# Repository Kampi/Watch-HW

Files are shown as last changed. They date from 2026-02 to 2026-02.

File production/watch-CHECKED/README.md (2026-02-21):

<p align="center" width="100%">
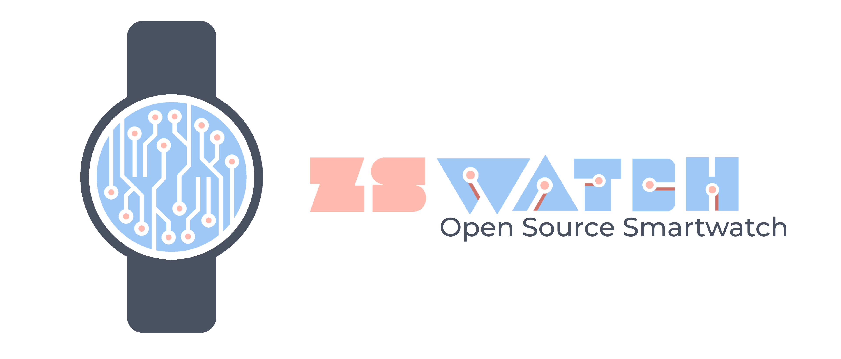
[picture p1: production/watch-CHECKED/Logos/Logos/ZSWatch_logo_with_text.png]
  
</p>

<h1 align="center">Watch-DevKit-HW</h1>

<p align="center" width="100%">
  <a href="https://github.com/ZSWatch/Watch-DevKit-HW/actions/workflows/watch.yaml">
    
  </a>
</p>

***

<p align="center">
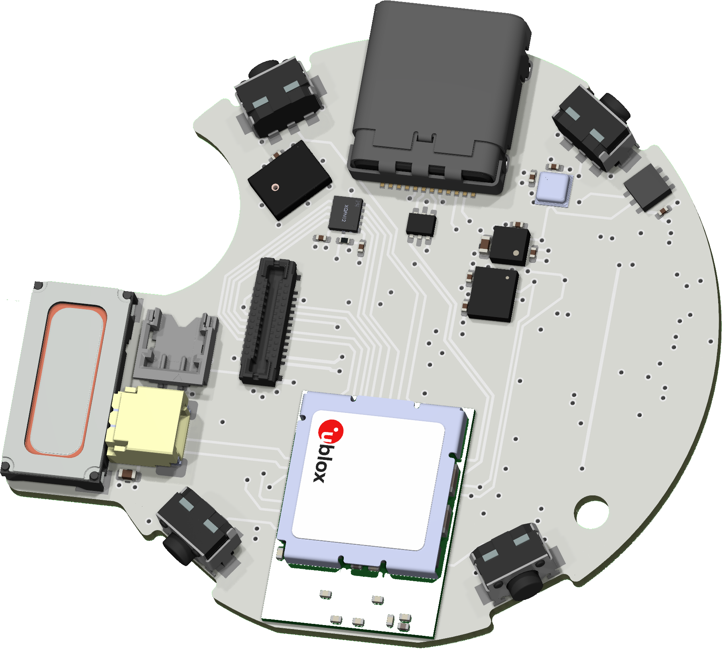
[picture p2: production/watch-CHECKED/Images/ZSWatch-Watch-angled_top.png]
3D Top Angled
  
&nbsp; &nbsp; &nbsp; &nbsp;
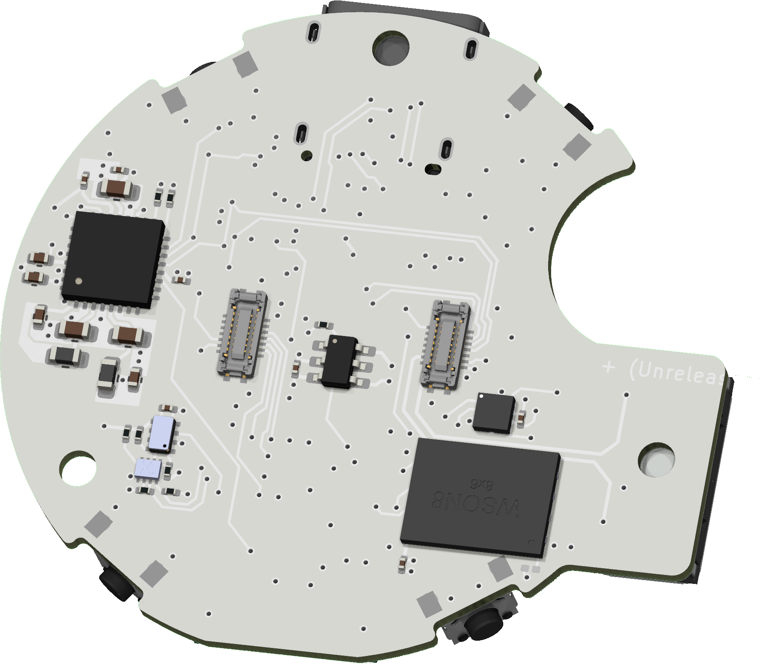
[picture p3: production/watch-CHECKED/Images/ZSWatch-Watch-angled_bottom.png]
3D Bottom Angled
  
</p>

***

## SPECIFICATIONS

| Parameter | Value |
| --- | --- |
| Dimensions | 40.97 × 37.5 mm |

***

## DIRECTORY STRUCTURE

    .
    ├─ Computations       # Misc calculations
    ├─ HTML               # HTML files for generated webpage
    ├─ Images             # Pictures and renders
    │
    ├─ kibot_resources    # External resources for KiBot
    │  ├─ colors          # Color theme for KiCad
    │  ├─ fonts           # Fonts used in the project
    │  ├─ scripts         # External scripts used with KiBot
    │  └─ templates       # Templates for KiBot generated reports
    │
    ├─ kibot_yaml         # KiBot YAML config files
    ├─ KiRI               # KiRI (PCB diff viewer) files
    │
    ├─ lib                # KiCad footprint and symbol libraries
    │  ├─ 3d_models       # Component 3D models
    │  ├─ lib_fp          # Footprint libraries
    │  └─ lib_sym         # Symbol libraries
    │
    ├─ logos              # Logos
    │
    ├─ Manufacturing      # Assembly and fabrication documents
    │  ├─ Assembly        # Assembly documents (BoM, pos, notes)
    │  │
    │  └─ Fabrication     # Fabrication documents (ZIP, notes)
    │     ├─ Drill Tables # CSV drill tables
    │     └─ Gerbers      # Gerbers
    │
    ├─ Report             # Reports for ERC/DRC
    ├─ Schematic          # PDF of schematic
    ├─ templates          # Title block templates
    ├─ Testing
    │  └─ Testpoints      # Testpoints tables
    │
    └─ Variants           # Outputs for assembly variants

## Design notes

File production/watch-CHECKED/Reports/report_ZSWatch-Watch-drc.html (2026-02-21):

Logo

| DRC report for ZSWatch-Watch
| PCB: ZSWatch-Watch Revision: + (Unreleased) Date: 2026-02-21T13:06:36+0000 KiCad Version: 9.0.7 | Errors: 1 Warnings: 65 Total: 66

Violations

Type | Description | Details
copper_edge_clearance | Board edge clearance violation (board setup constraints edge clearance 0.1250 mm; actual 0.0000 mm) | @(185.005263 mm, 138.299996 mm): Segment on Edge.Cuts @(187.425537 mm, 138.528148 mm): PCB text '+ (Unreleased)' on B.Cu
lib_footprint_issues | The current configuration does not include the footprint library 'Package_QFN'. | @(202.45 mm, 131.19 mm): Footprint IC604
lib_footprint_mismatch | Footprint 'C_0201_0603Metric' does not match copy in library 'Capacitor_SMD'. | @(203.7 mm, 133.1 mm): Footprint C603
lib_footprint_issues | The current configuration does not include the footprint library 'Wuerth'. | @(216.7 mm, 124.7 mm): Footprint S501
lib_footprint_mismatch | Footprint 'C_0201_0603Metric' does not match copy in library 'Capacitor_SMD'. | @(210.507497 mm, 136.062499 mm): Footprint C504
lib_footprint_mismatch | Footprint 'C_0402_1005Metric' does not match copy in library 'Capacitor_SMD'. | @(192.325 mm, 148.675 mm): Footprint C403
lib_footprint_issues | The current configuration does not include the footprint library 'Wuerth'. | @(197.409401 mm, 152.152416 mm): Footprint S504
lib_footprint_mismatch | Footprint 'C_0201_0603Metric' does not match copy in library 'Capacitor_SMD'. | @(201.23 mm, 132.79 mm): Footprint C604
lib_footprint_mismatch | Footprint 'C_0201_0603Metric' does not match copy in library 'Capacitor_SMD'. | @(213.976079 mm, 132.307498 mm): Footprint C507
lib_footprint_mismatch | Footprint 'R_0201_0603Metric' does not match copy in library 'Resistor_SMD'. | @(202.63 mm, 132.79 mm): Footprint R613
lib_footprint_mismatch | Footprint 'C_0201_0603Metric' does not match copy in library 'Capacitor_SMD'. | @(210.462496 mm, 134.237499 mm): Footprint C503
lib_footprint_mismatch | Footprint 'C_0201_0603Metric' does not match copy in library 'Capacitor_SMD'. | @(214.282501 mm, 126.8575 mm): Footprint C509
lib_footprint_mismatch | Footprint 'C_0201_0603Metric' does not match copy in library 'Capacitor_SMD'. | @(213.100001 mm, 127.675001 mm): Footprint C508
lib_footprint_issues | The current configuration does not include the footprint library 'EastRising'. | @(199.0 mm, 138.5 mm): Footprint X608
lib_footprint_issues | The current configuration does not include the footprint library 'Package_LGA_Kampi'. | @(212.1 mm, 135.2 mm): Footprint IC502
lib_footprint_issues | The current configuration does not include the footprint library 'Wuerth'. | @(216.6 mm, 152.1 mm): Footprint S502
lib_footprint_mismatch | Footprint 'C_0201_0603Metric' does not match copy in library 'Capacitor_SMD'. | @(212.78 mm, 130.667001 mm): Footprint C505
lib_footprint_mismatch | Footprint 'C_0201_0603Metric' does not match copy in library 'Capacitor_SMD'. | @(197.675287 mm, 128.024713 mm): Footprint C502
lib_footprint_issues | The current configuration does not include the footprint library 'Package_LGA_Kampi'. | @(214.500001 mm, 128.2375 mm): Footprint IC504
lib_footprint_mismatch | Footprint 'JST_SH_SM02B-SRSS-TB_1x02-1MP_P1.00mm_Horizontal' does not match copy in library 'Connector_JST'. | @(192.9 mm, 146.0 mm): Footprint X402
lib_footprint_mismatch | Footprint 'SOT-666' does not match copy in library 'Package_TO_SOT_SMD'. | @(207.0375 mm, 131.35 mm): Footprint IC602
lib_footprint_issues | The current configuration does not include the footprint library 'Molex'. | @(193.95 mm, 140.8 mm): Footprint X509
lib_footprint_issues | The current configuration does not include the footprint library 'Wuerth'. | @(197.433306 mm, 124.890678 mm): Footprint S503
lib_footprint_issues | The current configuration does not include the footprint library 'Knowles'. | @(198.820801 mm, 129.566207 mm): Footprint MK501
lib_footprint_issues | The current configuration does not include the footprint library 'Package_LGA_Kampi'. | @(212.604999 mm, 132.15 mm): Footprint IC503
lib_footprint_issues | The current configuration does not include the footprint library 'Broadcom'. | @(220.146966 mm, 127.633273 mm): Footprint IC501
lib_footprint_issues | The current configuration does not include the footprint library 'uBlox'. | @(207.0 mm, 150.1 mm): Footprint M601
lib_footprint_mismatch | Footprint 'C_0402_1005Metric' does not match copy in library 'Capacitor_SMD'. | @(211.054999 mm, 132.1875 mm): Footprint C506
lib_footprint_mismatch | Footprint 'USB_C_Receptacle_Amphenol_12401610E4-2A' does not match copy in library 'Connector_USB'. | @(207.0 mm, 123.9 mm): Footprint X603
lib_footprint_mismatch | Footprint 'C_0201_0603Metric' does not match copy in library 'Capacitor_SMD'. | @(221.234143 mm, 128.879548 mm): Footprint C501
lib_footprint_issues | The current configuration does not include the footprint library 'Same Sky'. | @(188.0 mm, 143.8 mm): Footprint LS801
lib_footprint_issues | The current configuration does not include the footprint library 'Package_QFN'. | @(197.4 mm, 142.15 mm): Footprint IC505
lib_footprint_mismatch | Footprint 'C_0201_0603Metric' does not match copy in library 'Capacitor_SMD'. | @(216.3304 mm, 136.3 mm): Footprint C402
lib_footprint_mismatch | Footprint 'R_0201_0603Metric' does not match copy in library 'Resistor_SMD'. | @(207.9 mm, 138.0 mm): Footprint R601
lib_footprint_mismatch | Footprint 'R_0201_0603Metric' does not match copy in library 'Resistor_SMD'. | @(216.209999 mm, 148.7 mm): Footprint R501
lib_footprint_mismatch | Footprint 'R_0201_0603Metric' does not match copy in library 'Resistor_SMD'. | @(217.8 mm, 145.5 mm): Footprint R506
lib_footprint_mismatch | Footprint 'R_0201_0603Metric' does not match copy in library 'Resistor_SMD'. | @(214.755 mm, 148.6 mm): Footprint R502
lib_footprint_mismatch | Footprint 'C_0201_0603Metric' does not match copy in library 'Capacitor_SMD'. | @(209.0 mm, 140.7 mm): Footprint C601
lib_footprint_mismatch | Footprint 'C_0201_0603Metric' does not match copy in library 'Capacitor_SMD'. | @(215.755 mm, 143.8 mm): Footprint C511
lib_footprint_mismatch | Footprint 'C_0201_0603Metric' does not match copy in library 'Capacitor_SMD'. | @(220.9 mm, 130.3 mm): Footprint C401
lib_footprint_mismatch | Footprint 'C_0201_0603Metric' does not match copy in library 'Capacitor_SMD'. | @(201.05 mm, 151.355 mm): Footprint C602
lib_footprint_mismatch | Footprint 'C_0603_1608Metric' does not match copy in library 'Capacitor_SMD'. | @(220.761401 mm, 131.497172 mm): Footprint C410
lib_footprint_mismatch | Footprint 'C_0201_0603Metric' does not match copy in library 'Capacitor_SMD'. | @(195.9 mm, 142.2 mm): Footprint C510
lib_footprint_mismatch | Footprint 'C_0603_1608Metric' does not match copy in library 'Capacitor_SMD'. | @(218.622001 mm, 139.936383 mm): Footprint C409
lib_footprint_issues | The current configuration does not include the footprint library 'Amphenol'. | @(200.8 mm, 138.5 mm): Footprint X702
lib_footprint_mismatch | Footprint 'C_0402_1005Metric' does not match copy in library 'Capacitor_SMD'. | @(224.5 mm, 137.1 mm): Footprint C512
lib_footprint_mismatch | Footprint 'C_0402_1005Metric' does not match copy in library 'Capacitor_SMD'. | @(217.892001 mm, 142.308382 mm): Footprint C406
lib_footprint_mismatch | Footprint 'R_0201_0603Metric' does not match copy in library 'Resistor_SMD'. | @(193.87 mm, 150.8 mm): Footprint R612
lib_footprint_mismatch | Footprint 'C_0402_1005Metric' does not match copy in library 'Capacitor_SMD'. | @(224.400001 mm, 135.950002 mm): Footprint C404
lib_footprint_mismatch | Footprint 'L_0603_1608Metric' does not match copy in library 'Inductor_SMD'. | @(221.911 mm, 141.5 mm): Footprint L402
lib_footprint_issues | The current configuration does not include the footprint library 'Package_SON_Kampi'. | @(216.18 mm, 147.5 mm): Footprint IC506
lib_footprint_mismatch | Footprint 'R_0201_0603Metric' does not match copy in library 'Resistor_SMD'. | @(215.109999 mm, 147.420001 mm): Footprint R505
lib_footprint_mismatch | Footprint 'R_0201_0603Metric' does not match copy in library 'Resistor_SMD'. | @(217.75 mm, 131.608381 mm): Footprint R408
lib_footprint_mismatch | Footprint 'C_0402_1005Metric' does not match copy in library 'Capacitor_SMD'. | @(223.8304 mm, 139.278193 mm): Footprint C408
lib_footprint_mismatch | Footprint 'QFN-32-1EP_5x5mm_P0.5mm_EP3.6x3.6mm' does not match copy in library 'Package_DFN_QFN'. | @(220.2 mm, 135.7 mm): Footprint IC401
lib_footprint_mismatch | Footprint 'TSOT-23-6' does not match copy in library 'Package_TO_SOT_SMD'. | @(206.5375 mm, 140.15 mm): Footprint IC601
lib_footprint_mismatch | Footprint 'WSON-8-1EP_8x6mm_P1.27mm_EP3.4x4.3mm' does not match copy in library 'Package_SON'. | @(197.3 mm, 147.135 mm): Footprint IC603
lib_footprint_mismatch | Footprint 'C_0603_1608Metric' does not match copy in library 'Capacitor_SMD'. | @(221.657 mm, 139.936383 mm): Footprint C407
lib_footprint_mismatch | Footprint 'L_0603_1608Metric' does not match copy in library 'Inductor_SMD'. | @(219.370999 mm, 142.349382 mm): Footprint L401
lib_footprint_issues | The current configuration does not include the footprint library 'Micro Crystal'. | @(215.755 mm, 145.430001 mm): Footprint IC507
lib_footprint_mismatch | Footprint 'R_0201_0603Metric' does not match copy in library 'Resistor_SMD'. | @(217.1 mm, 145.5 mm): Footprint R504
lib_footprint_mismatch | Footprint 'R_0201_0603Metric' does not match copy in library 'Resistor_SMD'. | @(218.449999 mm, 131.608381 mm): Footprint R407
lib_footprint_mismatch | Footprint 'C_0201_0603Metric' does not match copy in library 'Capacitor_SMD'. | @(222.730398 mm, 131.087793 mm): Footprint C405
lib_footprint_issues | The current configuration does not include the footprint library 'Amphenol'. | @(212.3 mm, 139.1 mm): Footprint X701

Schematic parity

Type | Description | Details
footprint_symbol_mismatch | Connector_JST:JST_SH_SM02B-SRSS-TB_1x02-1MP_P1.00mm_Horizontal doesn't match footprint given by symbol (JST_SH_SM02B-SRSS-TB_1x02-1MP_P1.00mm_Horizontal). | @(192.9 mm, 146.0 mm): Footprint X402
extra_footprint | Extra footprint | @(220.2 mm, 147.8 mm): Footprint REF**

Generated by KiBot (https://github.com/INTI-CMNB/KiBot/) v1.8.5

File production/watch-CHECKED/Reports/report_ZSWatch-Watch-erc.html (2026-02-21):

Logo

| ERC report for ZSWatch-Watch
| Schematic: ZSWatch-Watch Revision: + (Unreleased) Date: 2026-02-21T13:06:34+0000 KiCad Version: 9.0.7 | Errors: 0 Warnings: 49 Total: 49

Sheet / (ZSWatch-Watch.kicad_sch)

Type | Description | Details
unresolved_variable | Unresolved text variable | @(0.2032 mm, 0.3175 mm): Text Box
unresolved_variable | Unresolved text variable | @(0.2286 mm, 0.3556 mm): Text Box
unresolved_variable | Unresolved text variable | @(0.8636 mm, 0.3175 mm): Text Box
unresolved_variable | Unresolved text variable | @(0.889 mm, 0.3556 mm): Text Box
unresolved_variable | Unresolved text variable | @(1.524 mm, 0.3175 mm): Text Box
unresolved_variable | Unresolved text variable | @(1.5494 mm, 0.3556 mm): Text Box
unresolved_variable | Unresolved text variable | @(2.1844 mm, 0.3175 mm): Text Box
unresolved_variable | Unresolved text variable | @(2.2098 mm, 0.3556 mm): Text Box
footprint_link_issues | The current configuration does not include the footprint library 'Broadcom'. | @(0.3048 mm, 0.5461 mm): Symbol IC501 [APDS-9306-065]
footprint_link_issues | The current configuration does not include the footprint library 'Wuerth'. | @(0.254 mm, 1.0033 mm): Symbol S501 [SW_Push]
footprint_link_issues | The current configuration does not include the footprint library 'Wuerth'. | @(0.254 mm, 1.1176 mm): Symbol S502 [SW_Push]
footprint_link_issues | The current configuration does not include the footprint library 'Wuerth'. | @(0.254 mm, 1.2319 mm): Symbol S503 [SW_Push]
footprint_link_issues | The current configuration does not include the footprint library 'Wuerth'. | @(0.254 mm, 1.3462 mm): Symbol S504 [SW_Push]
footprint_link_issues | The current configuration does not include the footprint library 'Knowles'. | @(0.8636 mm, 1.27 mm): Symbol MK501 [SPK0641HT4H-1]
lib_symbol_issues | The current configuration does not include the symbol library 'Knowles' | @(0.8636 mm, 1.27 mm): Symbol MK501 [SPK0641HT4H-1]
footprint_link_issues | The current configuration does not include the footprint library 'Package_LGA_Kampi'. | @(1.9558 mm, 0.7747 mm): Symbol IC502 [BMI270]
lib_symbol_issues | The current configuration does not include the symbol library 'Bosch_Kampi' | @(1.9558 mm, 0.7747 mm): Symbol IC502 [BMI270]
footprint_link_issues | The current configuration does not include the footprint library 'Package_LGA_Kampi'. | @(2.7051 mm, 0.762 mm): Symbol IC504 [BMP581]
lib_symbol_issues | The current configuration does not include the symbol library 'Bosch_Kampi' | @(2.7051 mm, 0.762 mm): Symbol IC504 [BMP581]
footprint_link_issues | The current configuration does not include the footprint library 'Package_LGA_Kampi'. | @(2.6162 mm, 1.5875 mm): Symbol IC503 [LIS2MDLTR]
lib_symbol_issues | The current configuration does not include the symbol library 'ST' | @(2.6162 mm, 1.5875 mm): Symbol IC503 [LIS2MDLTR]
footprint_link_issues | The current configuration does not include the footprint library 'Package_QFN'. | @(3.3782 mm, 0.6096 mm): Symbol IC505 [DRV2603RUNT]
lib_symbol_issues | The current configuration does not include the symbol library 'Texas Instruments' | @(3.3782 mm, 0.6096 mm): Symbol IC505 [DRV2603RUNT]
footprint_link_issues | The current configuration does not include the footprint library 'Molex'. | @(3.6068 mm, 0.6223 mm): Symbol X509 [Conn_01x02]
footprint_link_issues | The current configuration does not include the footprint library 'Package_SON_Kampi'. | @(3.4544 mm, 1.3081 mm): Symbol IC506 [PCA9306JK]
lib_symbol_issues | The current configuration does not include the symbol library 'NXP' | @(3.4544 mm, 1.3081 mm): Symbol IC506 [PCA9306JK]
footprint_link_issues | The current configuration does not include the footprint library 'Micro Crystal'. | @(3.81 mm, 1.3843 mm): Symbol IC507 [RV-8263-C8]
lib_symbol_issues | The current configuration does not include the symbol library 'Micro Crystal' | @(3.81 mm, 1.3843 mm): Symbol IC507 [RV-8263-C8]
footprint_link_issues | The current configuration does not include the footprint library 'uBlox'. | @(0.8636 mm, 1.1049 mm): Symbol M601 [NORA-B106]
lib_symbol_issues | The current configuration does not include the symbol library 'uBlox' | @(0.8636 mm, 1.1049 mm): Symbol M601 [NORA-B106]
footprint_link_issues | The current configuration does not include the footprint library 'uBlox'. | @(1.397 mm, 1.0287 mm): Symbol M601 [NORA-B106]
lib_symbol_issues | The current configuration does not include the symbol library 'uBlox' | @(1.397 mm, 1.0287 mm): Symbol M601 [NORA-B106]
lib_symbol_issues | The current configuration does not include the symbol library 'ON Semiconductor' | @(0.5334 mm, 1.9685 mm): Symbol IC601 [FAN5622]
footprint_link_issues | The current configuration does not include the footprint library 'uBlox'. | @(2.159 mm, 1.2319 mm): Symbol M601 [NORA-B106]
lib_symbol_issues | The current configuration does not include the symbol library 'uBlox' | @(2.159 mm, 1.2319 mm): Symbol M601 [NORA-B106]
lib_symbol_issues | The current configuration does not include the symbol library 'Infineon' | @(2.3749 mm, 1.9939 mm): Symbol IC603 [S25FS512SAGNFI010]
footprint_link_issues | The current configuration does not include the footprint library 'Package_QFN'. | @(3.5179 mm, 0.762 mm): Symbol IC604 [NTS0104GU12 (XQFN12)]
lib_symbol_issues | The current configuration does not include the symbol library 'NXP' | @(3.5179 mm, 0.762 mm): Symbol IC604 [NTS0104GU12 (XQFN12)]
footprint_link_issues | The current configuration does not include the footprint library 'EastRising'. | @(3.5433 mm, 1.4605 mm): Symbol X608 [GC9A01A_CST816S]
lib_symbol_issues | The current configuration does not include the symbol library 'Display' | @(3.5433 mm, 1.4605 mm): Symbol X608 [GC9A01A_CST816S]
lib_symbol_issues | The current configuration does not include the symbol library 'Nordic' | @(1.7018 mm, 1.0414 mm): Symbol IC401 [nPM1300-QEXX]
footprint_link_issues | The current configuration does not include the footprint library ''. | @(1.9812 mm, 0.3683 mm): Symbol X402 [Conn_01x02]
footprint_link_issues | The current configuration does not include the footprint library 'Amphenol'. | @(0.9017 mm, 0.8636 mm): Symbol X701 [Conn_02x07_Top_Bottom]
footprint_link_issues | The current configuration does not include the footprint library 'Amphenol'. | @(1.5875 mm, 0.8636 mm): Symbol X702 [Conn_02x07_Top_Bottom]
footprint_link_issues | The current configuration does not include the footprint library 'Same Sky'. | @(1.8034 mm, 0.8255 mm): Symbol LS801 [Speaker]

Sheet /Project Architecture/Power Management/ (Power.kicad_sch)

Type | Description | Details
pin_to_pin | Pins of type Bidirectional and Power output are connected | @(2.032 mm, 1.2319 mm): Symbol IC401 Pin 29 [LSOUT1/VOUTLDO1, Bidirectional, Line] @(2.3114 mm, 1.2192 mm): Symbol #FLG0502 Pin 1 [Power output, Line]
pin_to_pin | Pins of type Bidirectional and Power output are connected | @(2.032 mm, 1.3081 mm): Symbol IC401 Pin 31 [LSOUT2/VOUTLDO2, Bidirectional, Line] @(2.159 mm, 1.2954 mm): Symbol #FLG0501 Pin 1 [Power output, Line]

Sheet /Project Architecture/Peripherals/ (Peripherals.kicad_sch)

Type | Description | Details
pin_to_pin | Pins of type Bidirectional and Power output are connected | @(1.8288 mm, 0.7239 mm): Symbol IC502 Pin 1 [SDO, Bidirectional, Line] @(0.889 mm, 1.8796 mm): Symbol #FLG0402 Pin 1 [Power output, Line]
pin_to_pin | Pins of type Bidirectional and Power output are connected | @(2.5781 mm, 0.7366 mm): Symbol IC504 Pin 5 [SDO, Bidirectional, Line] @(2.032 mm, 0.8255 mm): Symbol IC401 Pin 1 [VOUT1, Power output, Line]

Generated by KiBot (https://github.com/INTI-CMNB/KiBot/) v1.8.5

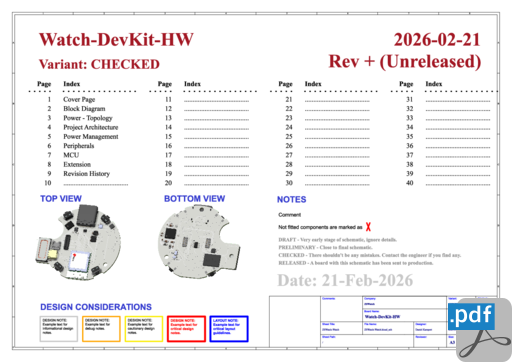
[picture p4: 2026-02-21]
production/watch-CHECKED/HTML/images/cat_pdf_schematic_ZSWatch-Watch-schematic.png

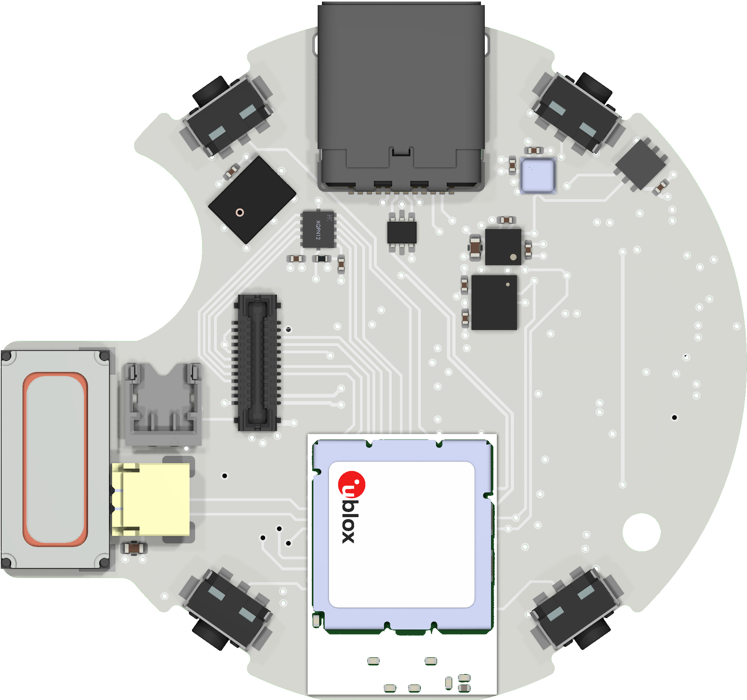
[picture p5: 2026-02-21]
production/watch-CHECKED/Images/ZSWatch-Watch-top.png

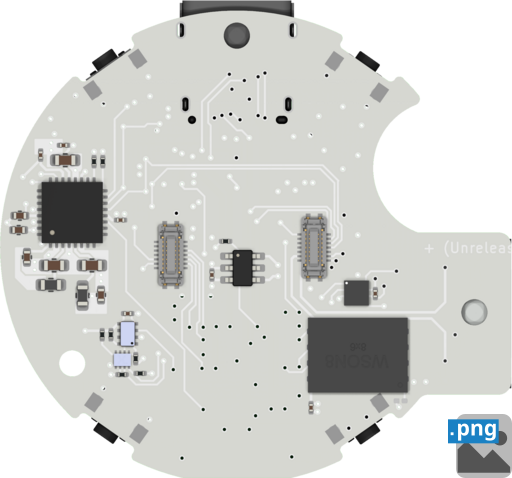
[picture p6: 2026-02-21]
production/watch-CHECKED/HTML/images/cat_png_3d_viewer_bottom_ZSWatch-Watch-bottom.png

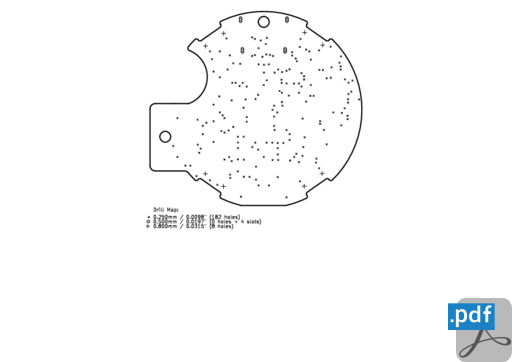
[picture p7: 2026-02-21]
production/watch-CHECKED/HTML/images/cat_pdf_drill_map_ZSWatch-Watch-PTH_drill_map.png

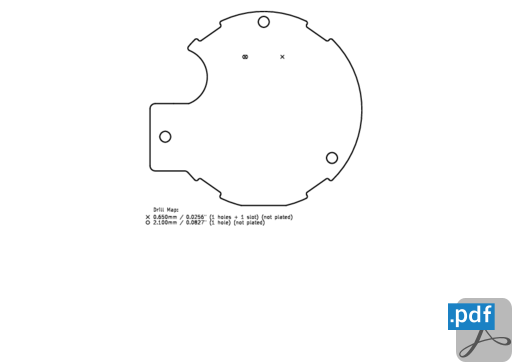
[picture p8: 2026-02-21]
production/watch-CHECKED/HTML/images/cat_pdf_drill_map_ZSWatch-Watch-NPTH_drill_map.png

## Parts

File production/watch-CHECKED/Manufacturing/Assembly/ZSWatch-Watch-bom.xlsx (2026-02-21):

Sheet: BoM
Bill of Materials
Schematic: | ZSWatch-Watch | Component Groups: | 37
Variant: | CHECKED | Component Count: | 62 (58 SMD/ 4 THT)
Revision: |  | Fitted Components: | 62 (58 SMD/ 4 THT)
Date: | 2025-07-13 | Number of PCBs: | 1
KiCad Version: | 9.0.7+1 | Total Components: | 62
Row | Quantity Per PCB | References | Value | Datasheet | Footprint | Description | manf | manf#
1 | 13 | C402 C501 C502 C503 C504 C507 C508 C509 C510 C511 C602 C603 C604 | 100n | https://datasheets.kyocera-avx.com/cx5r-KGM.pdf | C_0201_0603Metric | Unpolarized capacitor, small symbol | KYOCERA AVX | 02016D104MAT4A
2 | 1 | C505 | 220n | https://datasheets.kyocera-avx.com/cx5r-KGM.pdf | C_0201_0603Metric | Unpolarized capacitor, small symbol | KYOCERA AVX | 0201ZD224KAT2A
3 | 3 | C401 C405 C601 | 1u | https://datasheets.kyocera-avx.com/cx5r-KGM.pdf | C_0201_0603Metric | Unpolarized capacitor, small symbol | KYOCERA AVX | KGM03BR50J105KH
4 | 1 | C403 | 2u2 | https://datasheets.kyocera-avx.com/cx5r.pdf | C_0402_1005Metric | Unpolarized capacitor, small symbol | KYOCERA AVX | 0402ZD225MAT2A
5 | 5 | C404 C406 C408 C506 C512 | 10u | https://search.murata.co.jp/Ceramy/image/img/A01X/G101/ENG/GRJ155R60J106ME11-02A.pdf | C_0402_1005Metric | Unpolarized capacitor, small symbol | Murata Electronics | GRJ155R60J106ME11D
6 | 3 | C407 C409 C410 | 10u | https://datasheets.kyocera-avx.com/cx5r-KGM.pdf | C_0603_1608Metric | Unpolarized capacitor, small symbol | KYOCERA AVX | KGM15CR50J106MT
7 | 1 | IC501 | APDS-9306-065 | https://docs.broadcom.com/docs/AV02-4755EN | Broadcom_DFN-6_2x2mm_P0.65mm | Ambient Light Sensor, I2C interface, 1.7-3.6V, DFN-6 | Broadcom / Avago | APDS-9306-065
8 | 1 | IC502 | BMI270 | https://www.bosch-sensortec.com/media/boschsensortec/downloads/datasheets/bst-bmi270-ds000.pdf | Bosch_LGA-14_3x2.5mm_P0.5mm_LayoutBorder3x4y |  | Bosch | BMI270
9 | 1 | IC504 | BMP581 | https://www.bosch-sensortec.com/media/boschsensortec/downloads/datasheets/bst-bmp581-ds004.pdf | Bosch_LGA-10_2x2mm_P0.5mm_ClockwisePinNumbering |  | Bosch | BMP581
10 | 1 | IC505 | DRV2603RUNT | https://www.ti.com/lit/ds/symlink/drv2603.pdf?HQS=dis-mous-null-mousermode-dsf-pf-null-wwe&ts=1692200896697 | WQFN-10_2x2mm_P0.5mm |  | Texas Instruments | DRV2603RUNT
11 | 1 | IC601 | FAN5622SX | https://www.onsemi.com/download/data-sheet/pdf/fan5626-d.pdf | TSOT-23-6 |  | onsemi / Fairchild | FAN5622SX
12 | 1 | IC503 | LIS2MDLTR | http://www.st.com/content/ccc/resource/technical/document/datasheet/group3/29/13/d1/e0/9a/4d/4f/30/DM00395193/files/DM00395193.pdf/jcr:content/translations/en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 | LGA-12_2x2mm_P0.5mm |  | STMicroelectronics | LIS2MDLTR
13 | 1 | IC603 | MX25U51245GZ4I00 | https://www.mouser.de/datasheet/2/819/MX25U51245G_2c_1_8V_2c_512Mb_2c_v1_4-3371129.pdf | WSON-8-1EP_8x6mm_P1.27mm_EP3.4x4.3mm |  | Macronix | MX25U51245GZ4I00
14 | 1 | IC604 | NTS0104GU12 | https://www.nxp.com/docs/en/data-sheet/NTS0104.pdf | XQFN-12-1.7x2mm_P0.4mm |  | NXP Semiconductors | NTS0104GU12,115
15 | 1 | IC506 | PCA9306JK | https://www.nxp.com/docs/en/data-sheet/PCA9306.pdf | XSON-8_0.65x0.17mm_P0.35mm | Dual bidirectional I2C Bus and SMBus voltage level translator | NXP Semiconductors | PCA9306JKZ
16 | 1 | IC507 | RV-8263-C8 | https://www.microcrystal.com/fileadmin/Media/Products/RTC/Datasheet/RV-8263-C8.pdf | RV-8263-C8 |  | Micro Crystal | RV-8263-C8 32.768kHz-20PPM-TA-QA
17 | 1 | IC602 | USBLC6-2P6 | https://www.st.com/resource/en/datasheet/usblc6-2.pdf | SOT-666 | Very low capacitance ESD protection diode, 2 data-line, SOT-666 | STMicroelectronics | USBLC6-2P6
18 | 1 | IC401 | nPM1300-QEXX | https://infocenter.nordicsemi.com/index.jsp?topic=%2Fstruct_pmic%2Fstruct%2Fnpm1300.html | QFN-32-1EP_5x5mm_P0.5mm_EP3.6x3.6mm |  | Nordic Semiconductor | nPM1300-QEAA-R7
19 | 2 | L401 L402 | 2u2 | https://www.mouser.de/datasheet/3/76/1/JELF243B-9121.pdf | L_0603_1608Metric | Inductor | Murata Electronics | LQM18PZ2R2MDHD
20 | 1 | LS801 | Speaker | https://www.mouser.de/datasheet/3/6118/1/cmr_12062s_67.pdf | CMR-12062S-67 | Speaker | Same Sky | CMR-12062S-67
21 | 1 | M601 | NORA-B106 | https://www.u-blox.com/docs/UBX-20027119 | NORA-B106 |  | u-blox | NORA-B106-00B
22 | 1 | MK501 | SPK0641HT4H-1 | https://www.knowles.com/docs/default-source/default-document-library/sph0645lm4h-1-datasheet.pdf | SPK0641HT4H-1 | Digital MEMS Microphone | Knowles | SPK0641HT4H-1
23 | 2 | R501 R502 | 1k8 | https://www.mouser.com/catalog/specsheets/YAGEO_PYu_RC_Group_51_RoHS_L_12.pdf | R_0201_0603Metric | Resistor, small symbol | YAGEO | RC0201JR-071K8L
24 | 2 | R504 R505 | 3k3 | https://www.mouser.com/catalog/specsheets/YAGEO_PYu_RC_Group_51_RoHS_L_12.pdf | R_0201_0603Metric | Resistor, small symbol | YAGEO | RC0201JR-073K3L
25 | 1 | R601 | 12k | https://www.mouser.com/catalog/specsheets/YAGEO_PYu_RC_Group_51_RoHS_L_12.pdf | R_0201_0603Metric | Resistor, small symbol | YAGEO | RC0201JR-0712KL
26 | 1 | R407 | 47k | https://www.mouser.com/catalog/specsheets/YAGEO_PYu_RC_Group_51_RoHS_L_12.pdf | R_0201_0603Metric | Resistor, small symbol | YAGEO | RC0201JR-0747KL
27 | 2 | R408 R613 | 100k | https://www.mouser.com/catalog/specsheets/YAGEO_PYu_RC_Group_51_RoHS_L_12.pdf | R_0201_0603Metric | Resistor, small symbol | YAGEO | RC0201JR-07100KL
28 | 1 | R506 | 200k | https://www.mouser.com/catalog/specsheets/YAGEO_PYu_RC_Group_51_RoHS_L_12.pdf | R_0201_0603Metric | Resistor, small symbol | YAGEO | RC0201JR-07200KL
29 | 1 | S501 | SW1 | https://www.we-online.com/components/products/datasheet/436333033816.pdf | 43633303381_NoMountingPads | Push button switch, generic, two pins | Wurth Elektronik | 436333033816
30 | 1 | S502 | SW2 | https://www.we-online.com/components/products/datasheet/436333033816.pdf | 43633303381_NoMountingPads | Push button switch, generic, two pins | Wurth Elektronik | 436333033816
31 | 1 | S503 | SW3 | https://www.we-online.com/components/products/datasheet/436333033816.pdf | 43633303381_NoMountingPads | Push button switch, generic, two pins | Wurth Elektronik | 436333033816
32 | 1 | S504 | SW4 | https://www.we-online.com/components/products/datasheet/436333033816.pdf | 43633303381_NoMountingPads | Push button switch, generic, two pins | Wurth Elektronik | 436333033816
33 | 1 | X402 | Battery | https://www.mouser.com/catalog/specsheets/JST_SM02B-SRSS-TB_LF_SN_eSR_SZ.pdf | JST_SH_SM02B-SRSS-TB_1x02-1MP_P1.00mm_Horizontal | Generic connector, single row, 01x02, script generated (kicad-library-utils/schlib/autogen/connector/) | JST Commercial | SM02B-SRSS-TB
34 | 1 | X603 | Device | https://www.usb.org/sites/default/files/documents/usb_type-c.zip | USB_C_Receptacle_Amphenol_12401610E4-2A | USB Full-Featured Type-C Receptacle connector | Amphenol Commercial Products | 12401610E4#2A
35 | 1 | X608 | Display | https://www.buydisplay.com/download/manual/ER-TFT1.28-2_Datasheet.pdf | ER-CON0.4-24P |  | EastRising | OK-24F024-04
36 | 2 | X701 X702 | MB1 | https://cdn.amphenol-cs.com/media/wysiwyg/files/drawing/101r014fb110.pdf | 101R014FB110 | Generic connector, double row, 02x07, top/bottom pin numbering scheme (row 1: 1...pins_per_row, row2: pins_per_row+1 ... num_pins), script generated (kicad-library-utils/schlib/autogen/connector/) | Amphenol Aorora | 101R014FB110
37 | 1 | X509 | Motor | https://www.molex.com/en-us/products/part-detail-pdf/781710002?display=pdf | 78171-0002 | Generic connector, single row, 01x02, script generated (kicad-library-utils/schlib/autogen/connector/) | Molex | 78171-0002

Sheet: Costs
Bill of Materials
Schematic: | ZSWatch-Watch |  |  |  |  | Board Qty: | 1
Variant: | CHECKED |  |  |  |  | Unit Cost: | $0.00
Revision: |  |  |  |  |  | Total Cost: | $0.00 |  |  |  |  | $0.00 | 0 of 37 parts found
Date: | 2025-07-13
KiCad Version: | 9.0.7+1
Global Part Info |  |  |  |  |  |  |  | Mouser
References | Value | Footprint | Manf | Manf# | Build Quantity | Unit$ | Ext$ | Avail | Purch | Unit$ | MOQ | Ext$ | Cat#
C402 C501 C502 C503 C504 C507 C508 C509 C510 C511 C602 C603 C604 | 100n | C_0201_0603Metric | KYOCERA AVX | 02016D104MAT4A (https://datasheets.kyocera-avx.com/cx5r-KGM.pdf) | 13
C505 | 220n | C_0201_0603Metric | KYOCERA AVX | 0201ZD224KAT2A (https://datasheets.kyocera-avx.com/cx5r-KGM.pdf) | 1
C401 C405 C601 | 1u | C_0201_0603Metric | KYOCERA AVX | KGM03BR50J105KH (https://datasheets.kyocera-avx.com/cx5r-KGM.pdf) | 3
C403 | 2u2 | C_0402_1005Metric | KYOCERA AVX | 0402ZD225MAT2A (https://datasheets.kyocera-avx.com/cx5r.pdf) | 1
C404 C406 C408 C506 C512 | 10u | C_0402_1005Metric | Murata Electronics | GRJ155R60J106ME11D (https://search.murata.co.jp/Ceramy/image/img/A01X/G101/ENG/GRJ155R60J106ME11-02A.pdf) | 5
C407 C409 C410 | 10u | C_0603_1608Metric | KYOCERA AVX | KGM15CR50J106MT (https://datasheets.kyocera-avx.com/cx5r-KGM.pdf) | 3
IC501 | APDS-9306-065 | Broadcom_DFN-6_2x2mm_P0.65mm | Broadcom / Avago | APDS-9306-065 (https://docs.broadcom.com/docs/AV02-4755EN) | 1
IC502 | BMI270 | Bosch_LGA-14_3x2.5mm_P0.5mm_LayoutBorder3x4y | Bosch | BMI270 (https://www.bosch-sensortec.com/media/boschsensortec/downloads/datasheets/bst-bmi270-ds000.pdf) | 1
IC504 | BMP581 | Bosch_LGA-10_2x2mm_P0.5mm_ClockwisePinNumbering | Bosch | BMP581 (https://www.bosch-sensortec.com/media/boschsensortec/downloads/datasheets/bst-bmp581-ds004.pdf) | 1
IC505 | DRV2603RUNT | WQFN-10_2x2mm_P0.5mm | Texas Instruments | DRV2603RUNT (https://www.ti.com/lit/ds/symlink/drv2603.pdf?HQS=dis-mous-null-mousermode-dsf-pf-null-wwe&ts=1692200896697) | 1
IC601 | FAN5622SX | TSOT-23-6 | onsemi / Fairchild | FAN5622SX (https://www.onsemi.com/download/data-sheet/pdf/fan5626-d.pdf) | 1
IC503 | LIS2MDLTR | LGA-12_2x2mm_P0.5mm | STMicroelectronics | LIS2MDLTR (http://www.st.com/content/ccc/resource/technical/document/datasheet/group3/29/13/d1/e0/9a/4d/4f/30/DM00395193/files/DM00395193.pdf/jcr:content/translations/en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) | 1
IC603 | MX25U51245GZ4I00 | WSON-8-1EP_8x6mm_P1.27mm_EP3.4x4.3mm | Macronix | MX25U51245GZ4I00 (https://www.mouser.de/datasheet/2/819/MX25U51245G_2c_1_8V_2c_512Mb_2c_v1_4-3371129.pdf) | 1
IC604 | NTS0104GU12 | XQFN-12-1.7x2mm_P0.4mm | NXP Semiconductors | NTS0104GU12,115 (https://www.nxp.com/docs/en/data-sheet/NTS0104.pdf) | 1
IC506 | PCA9306JK | XSON-8_0.65x0.17mm_P0.35mm | NXP Semiconductors | PCA9306JKZ (https://www.nxp.com/docs/en/data-sheet/PCA9306.pdf) | 1
IC507 | RV-8263-C8 | RV-8263-C8 | Micro Crystal | RV-8263-C8 32.768kHz-20PPM-TA-QA (https://www.microcrystal.com/fileadmin/Media/Products/RTC/Datasheet/RV-8263-C8.pdf) | 1
IC602 | USBLC6-2P6 | SOT-666 | STMicroelectronics | USBLC6-2P6 (https://www.st.com/resource/en/datasheet/usblc6-2.pdf) | 1
IC401 | nPM1300-QEXX | QFN-32-1EP_5x5mm_P0.5mm_EP3.6x3.6mm | Nordic Semiconductor | nPM1300-QEAA-R7 (https://infocenter.nordicsemi.com/index.jsp?topic=%2Fstruct_pmic%2Fstruct%2Fnpm1300.html) | 1
L401 L402 | 2u2 | L_0603_1608Metric | Murata Electronics | LQM18PZ2R2MDHD (https://www.mouser.de/datasheet/3/76/1/JELF243B-9121.pdf) | 2
LS801 | Speaker | CMR-12062S-67 | Same Sky | CMR-12062S-67 (https://www.mouser.de/datasheet/3/6118/1/cmr_12062s_67.pdf) | 1
M601 | NORA-B106 | NORA-B106 | u-blox | NORA-B106-00B (https://www.u-blox.com/docs/UBX-20027119) | 1
MK501 | SPK0641HT4H-1 | SPK0641HT4H-1 | Knowles | SPK0641HT4H-1 (https://www.knowles.com/docs/default-source/default-document-library/sph0645lm4h-1-datasheet.pdf) | 1
R501 R502 | 1k8 | R_0201_0603Metric | YAGEO | RC0201JR-071K8L (https://www.mouser.com/catalog/specsheets/YAGEO_PYu_RC_Group_51_RoHS_L_12.pdf) | 2
R504 R505 | 3k3 | R_0201_0603Metric | YAGEO | RC0201JR-073K3L (https://www.mouser.com/catalog/specsheets/YAGEO_PYu_RC_Group_51_RoHS_L_12.pdf) | 2
R601 | 12k | R_0201_0603Metric | YAGEO | RC0201JR-0712KL (https://www.mouser.com/catalog/specsheets/YAGEO_PYu_RC_Group_51_RoHS_L_12.pdf) | 1
R407 | 47k | R_0201_0603Metric | YAGEO | RC0201JR-0747KL (https://www.mouser.com/catalog/specsheets/YAGEO_PYu_RC_Group_51_RoHS_L_12.pdf) | 1
R408 R613 | 100k | R_0201_0603Metric | YAGEO | RC0201JR-07100KL (https://www.mouser.com/catalog/specsheets/YAGEO_PYu_RC_Group_51_RoHS_L_12.pdf) | 2
R506 | 200k | R_0201_0603Metric | YAGEO | RC0201JR-07200KL (https://www.mouser.com/catalog/specsheets/YAGEO_PYu_RC_Group_51_RoHS_L_12.pdf) | 1
S501 | SW1 | 43633303381_NoMountingPads | Wurth Elektronik | 436333033816 (https://www.we-online.com/components/products/datasheet/436333033816.pdf) | 1
S502 | SW2 | 43633303381_NoMountingPads | Wurth Elektronik | 436333033816 (https://www.we-online.com/components/products/datasheet/436333033816.pdf) | 1
S503 | SW3 | 43633303381_NoMountingPads | Wurth Elektronik | 436333033816 (https://www.we-online.com/components/products/datasheet/436333033816.pdf) | 1
S504 | SW4 | 43633303381_NoMountingPads | Wurth Elektronik | 436333033816 (https://www.we-online.com/components/products/datasheet/436333033816.pdf) | 1
X402 | Battery | JST_SH_SM02B-SRSS-TB_1x02-1MP_P1.00mm_Horizontal | JST Commercial | SM02B-SRSS-TB (https://www.mouser.com/catalog/specsheets/JST_SM02B-SRSS-TB_LF_SN_eSR_SZ.pdf) | 1
X603 | Device | USB_C_Receptacle_Amphenol_12401610E4-2A | Amphenol Commercial Products | 12401610E4#2A (https://www.usb.org/sites/default/files/documents/usb_type-c.zip) | 1
X608 | Display | ER-CON0.4-24P | EastRising | OK-24F024-04 (https://www.buydisplay.com/download/manual/ER-TFT1.28-2_Datasheet.pdf) | 1
X701 X702 | MB1 | 101R014FB110 | Amphenol Aorora | 101R014FB110 (https://cdn.amphenol-cs.com/media/wysiwyg/files/drawing/101r014fb110.pdf) | 2
X509 | Motor | 78171-0002 | Molex | 78171-0002 (https://www.molex.com/en-us/products/part-detail-pdf/781710002?display=pdf) | 1
 |  |  |  |  |  | Total Purchase: | $0.00 | Buy here (https://mouser.com/bom/) |  |  |  | $0.00
Created: | 2026-02-21 13:11:34 |  |  |  |  | Purchase description:
KiCost® v1.1.20 + KiBot v1.8.5

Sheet: Colors
Columns colors
KiCad Fields (default)
Generated Fields
User Fields
Empty Fields
Costs sheet colors
Best price
No manufacturer or distributor code
Not available
Purchase quantity is more than what is available
Minimum order quantity not respected
Total available part quantity is less than needed
Total purchased part quantity is less than needed
This part is obsolete
This part is listed but is not normally stocked

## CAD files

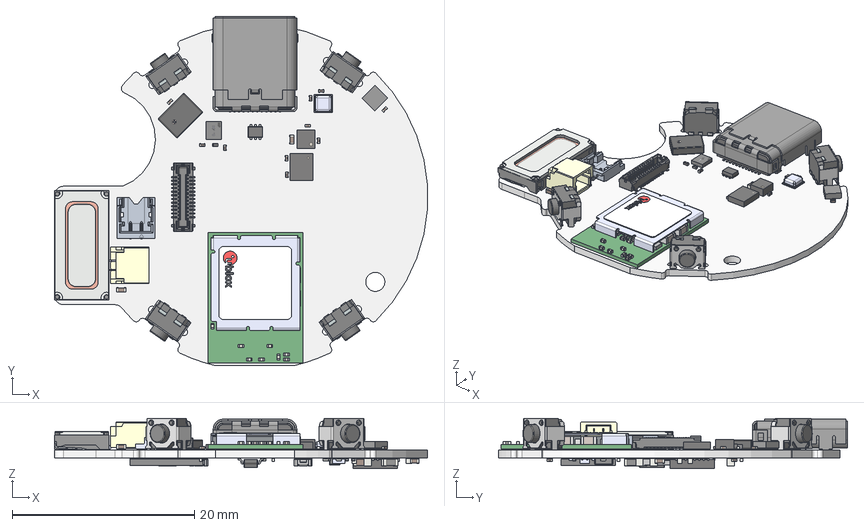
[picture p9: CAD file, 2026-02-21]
production/watch-CHECKED/3D/ZSWatch-Watch.step
40.9 x 38.3 x 5.54 mm
XQFN-12
C_0201_0603Metric x 17
frame x 4
stem x 4
cover_0 x 4
pins x 4
pin2 x 8
C_0402_1005Metric x 6
R_0201_0603Metric x 9
ER-CON0.4-24P
LGA-14_3x2.5mm_P0.5mm_LayoutBorder3x4y
BMP581
SM02B-SRSS-TB-LF-SN
SOT-666
SPK0641HT4H
LGA-12_2x2mm_P0.5mm
Pins
label_8x8
logo_x_4mm
logo_o_4mm
logo_l_4mm
logo_b_4mm
logo_u_4mm
UBXH04-0000650_NORA-TYPE-1_SHIELD_rev3
Extruded x 185
aQFN-116_(7x7) x 2
Free-Models
USB_C_Receptacle_Amphenol_12401610E4-2A
CMR-12062S-67
WQFN-10
C_0603_1608Metric x 3
BW94_SERIES x 2
L_0603_1608Metric x 2
SOT1089 LF
SOT1089 Mold body
QFN-32-5x5_0.5_EP3.6x3.6mm
TSOT-23-6
WSON-8-8x6
RV-8263-C8
kibot_46mx90a8_PCB

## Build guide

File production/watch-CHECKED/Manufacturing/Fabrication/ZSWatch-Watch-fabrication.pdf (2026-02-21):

# Top Fabrication (Scale 1:1)

# Watch-DevKit-HW Fabrication Document

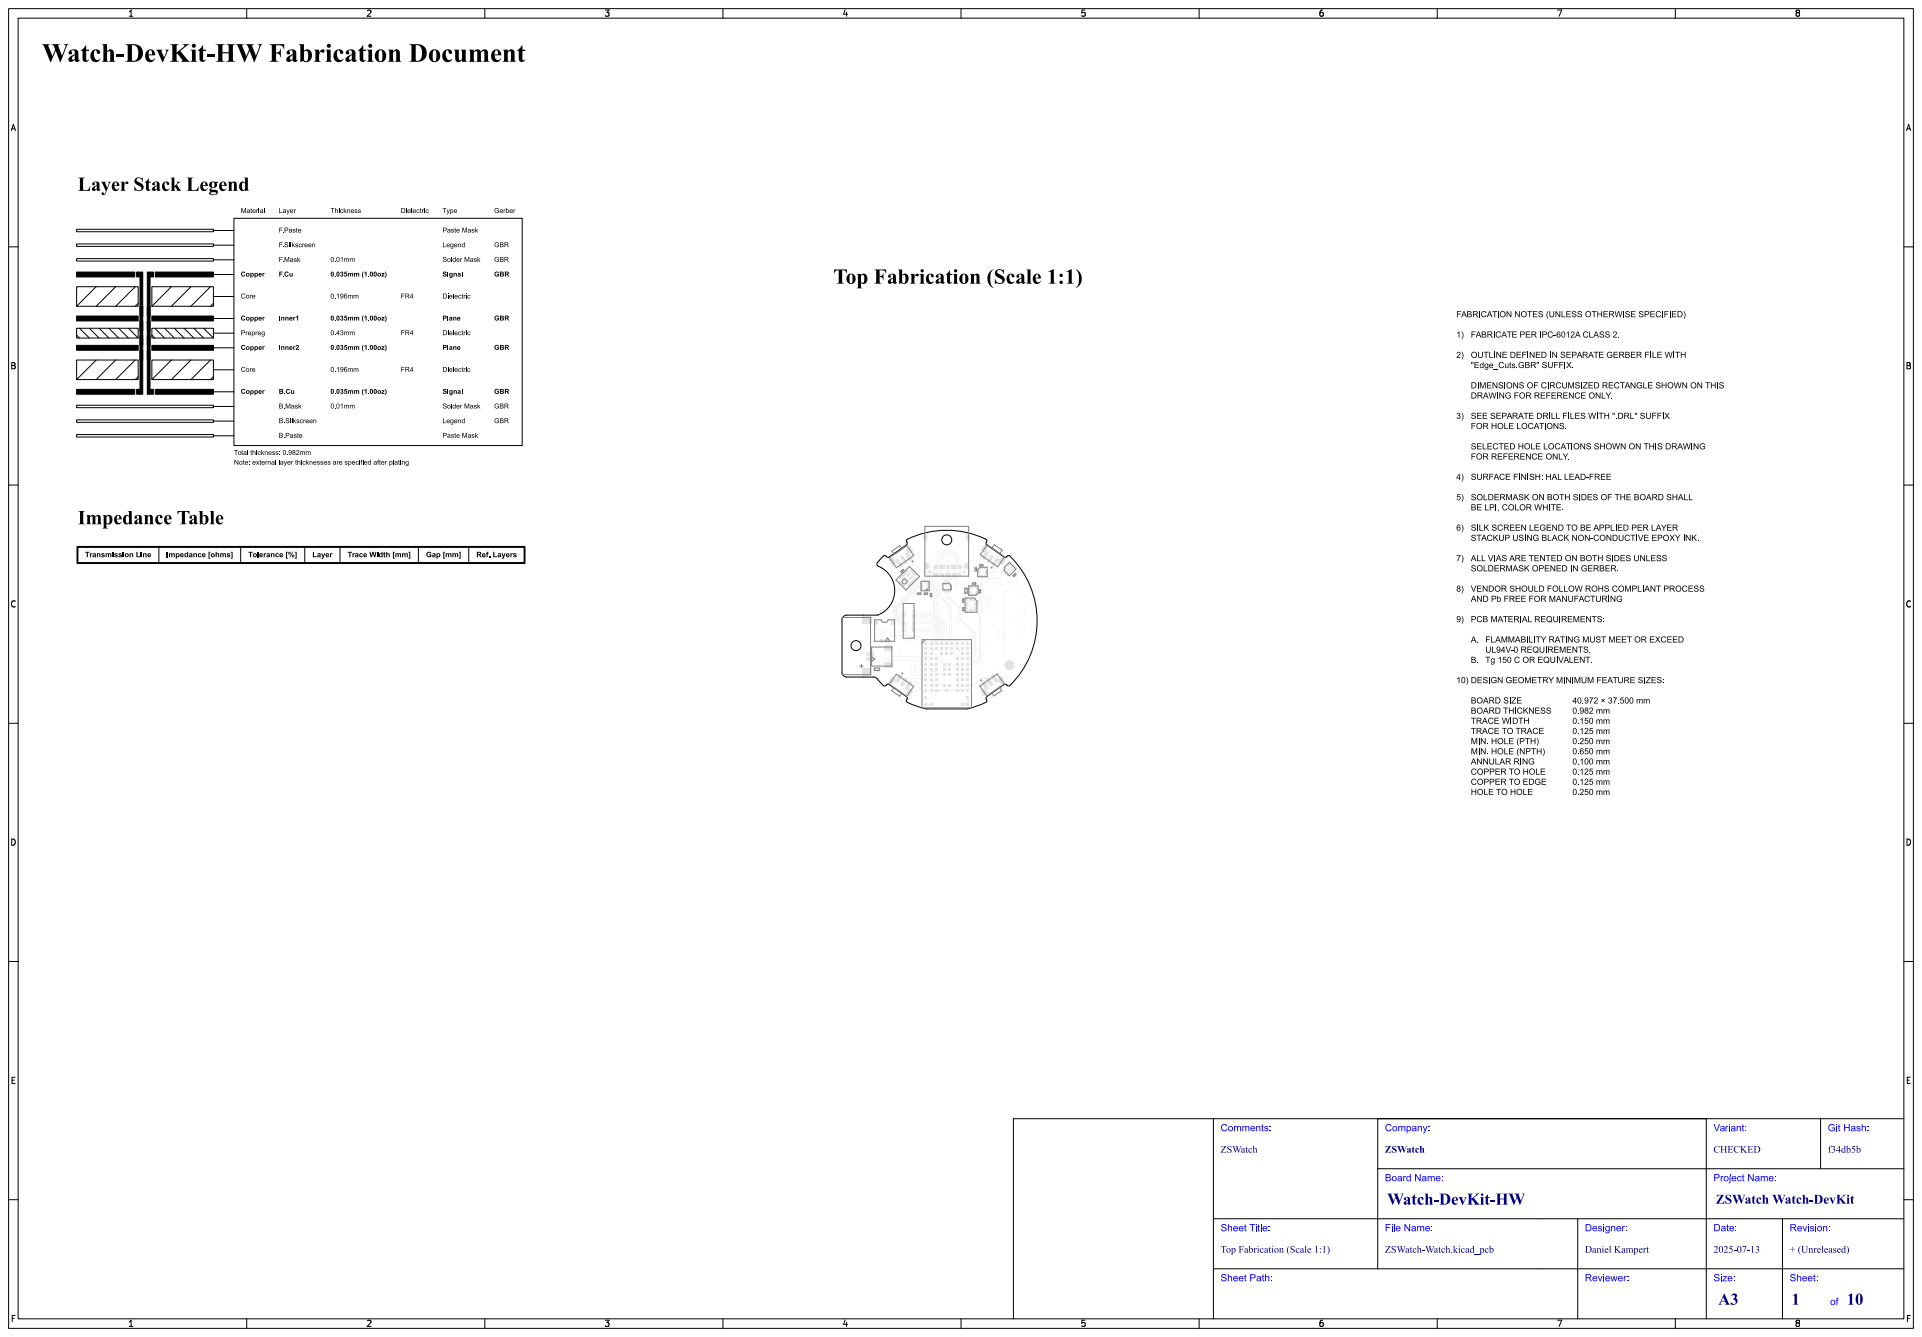
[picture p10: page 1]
Git Hash:; ZSWatch; Comments:; Sheet Path:; Sheet Title:; File Name:; Watch-DevKit-HW; ZSWatch Watch-DevKit; Company:; CHECKED; Variant:; Board Name:; ZSWatch-Watch.kicad_pcb; Daniel Kampert; Designer:; Reviewer:; Project Name:; Date:; + (Unreleased); Revision:; Size:; Sheet:

Top Fabrication (Scale 1:1)

# Bottom Fabrication (Scale 1:1)

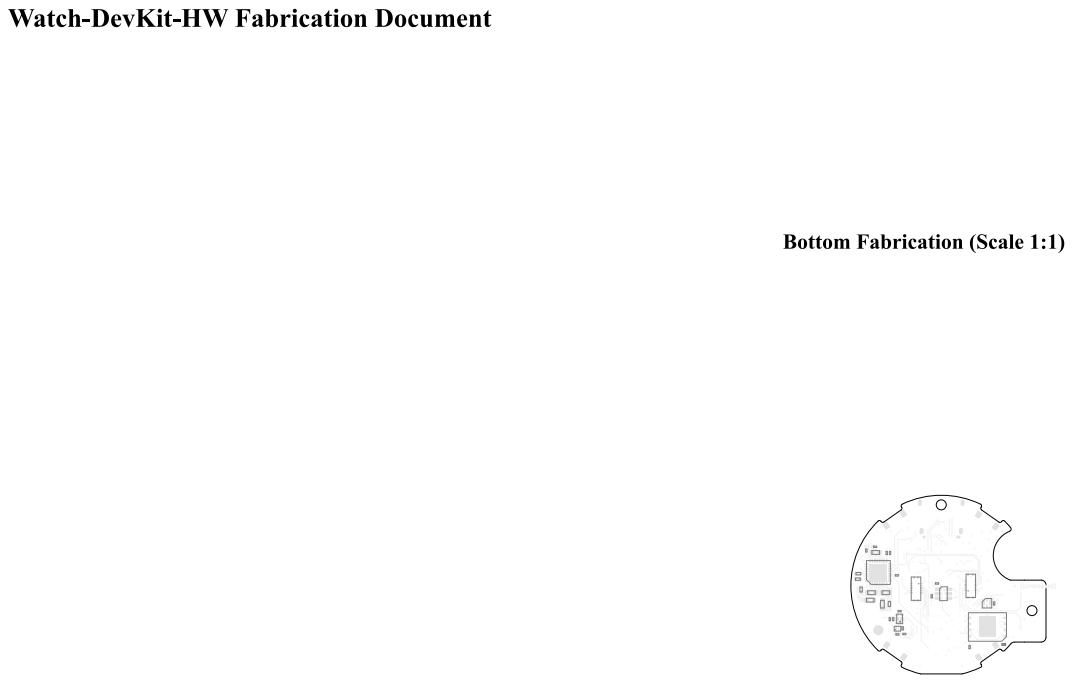
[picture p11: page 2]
Git; Hash:; ZSWatch; Comments:; Sheet Title:; File Name:; Watch-DevKit-HW; ZSWatch Watch-DevKit; Company:; CHECKED; Variant:; Board Name:; ZSWatch-Watch.kicad_pcb; Daniel Kampert; Designer:; Project Name:; Date:; + (Unreleased); Revision:

Bottom Fabrication (Scale 1:1)

# Drill Drawing L1 - L4 (Scale 1:1)

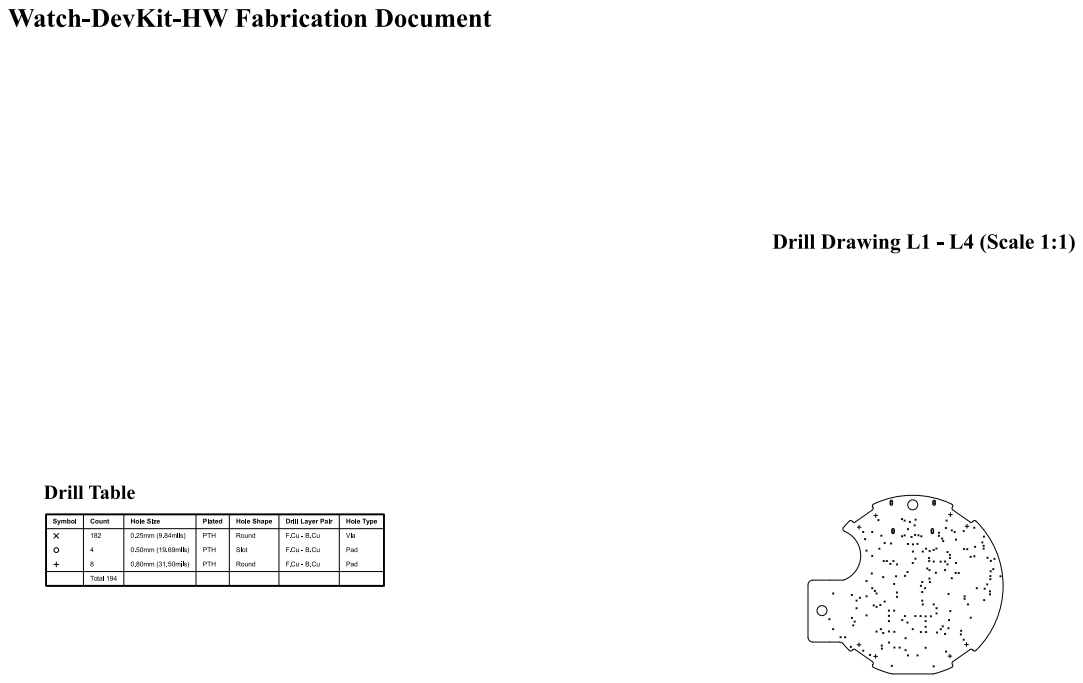
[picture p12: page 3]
Git; Hash:; ZSWatch; Comments:; Drill Drawing (L1 - L4); Sheet Title:; File Name:; Watch-DevKit-HW; ZSWatch Watch-DevKit; Company:; CHECKED; Variant:; Board Name:; ZSWatch-Watch.kicad_pcb; Daniel Kampert; Designer:; Project Name:; Date:; + (Unreleased); Revision:

# Drill Drawing L1 - L4 (Scale 1:1)

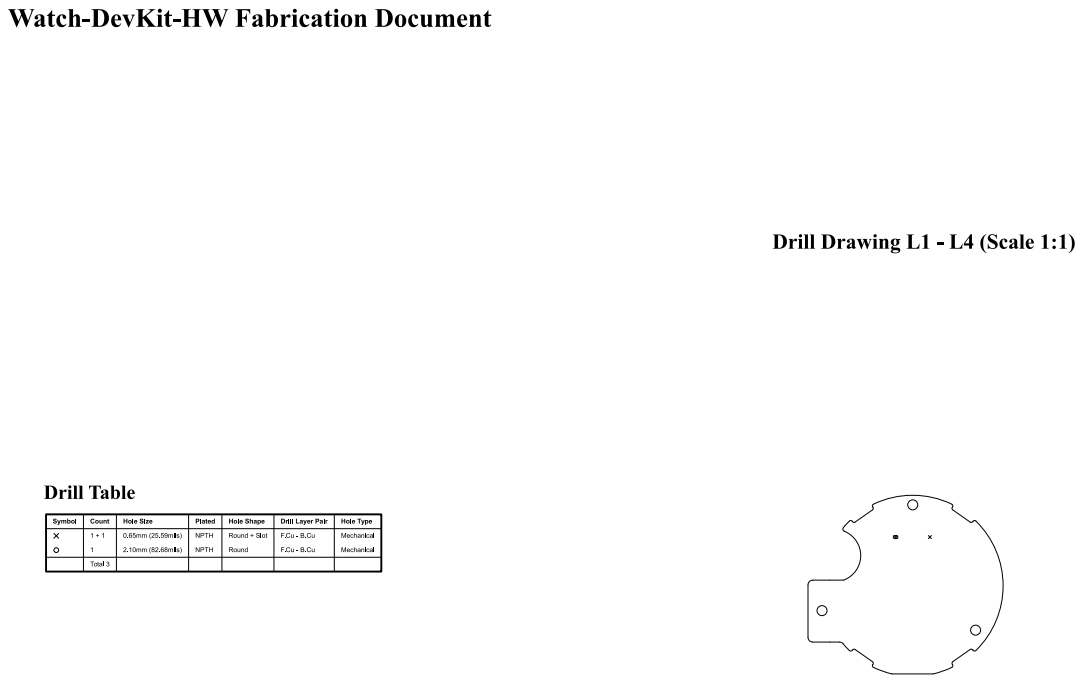
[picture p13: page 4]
Git; Hash:; ZSWatch; Comments:; Drill Drawing (L1 - L4); Sheet Title:; File Name:; Watch-DevKit-HW; ZSWatch Watch-DevKit; Company:; CHECKED; Variant:; Board Name:; ZSWatch-Watch.kicad_pcb; Daniel Kampert; Designer:; Project Name:; Date:; + (Unreleased); Revision:

# Top Test Points (Scale 1:1)

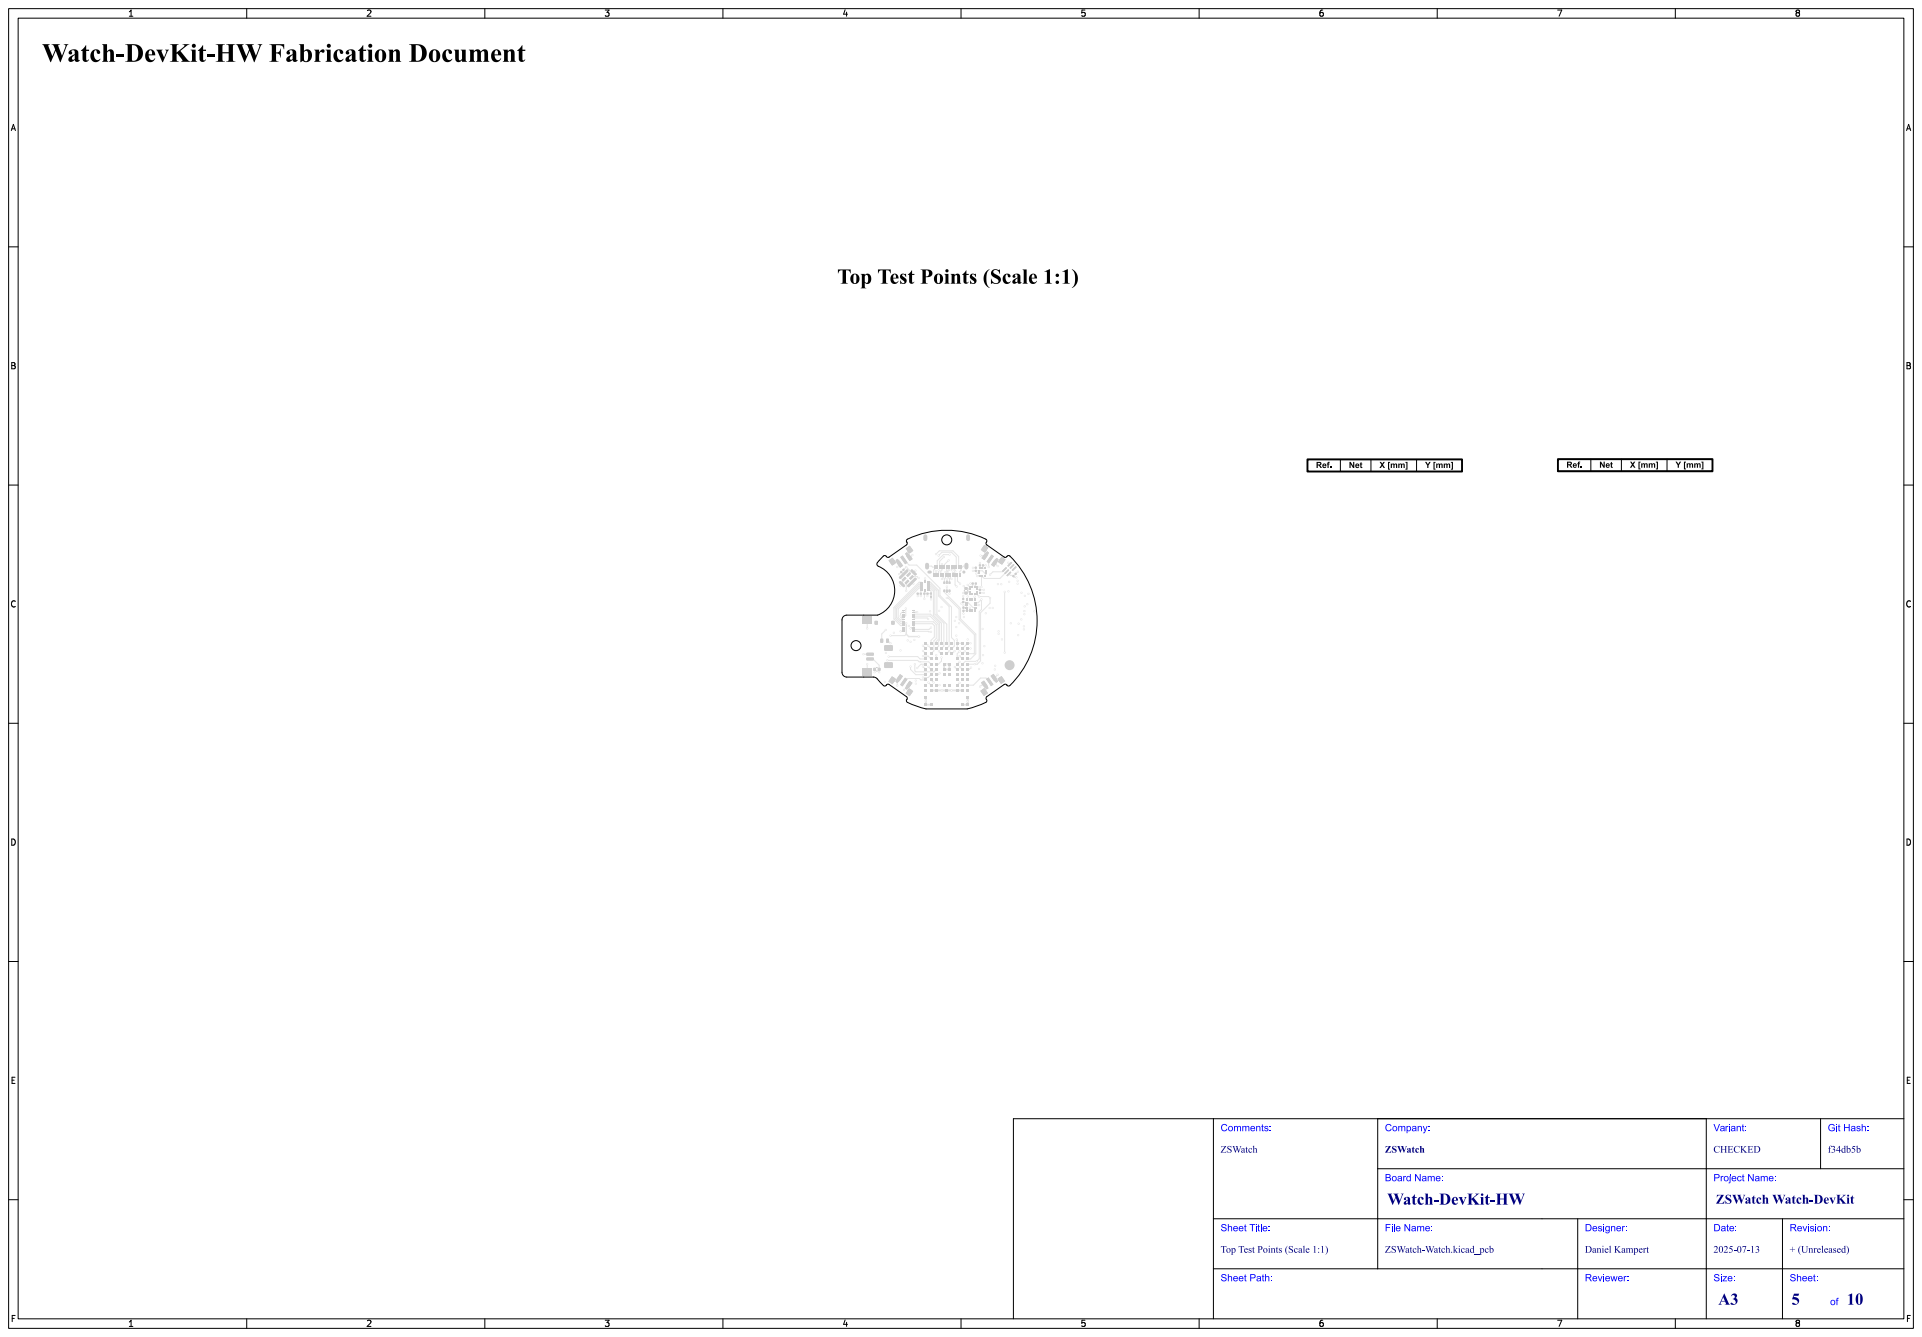
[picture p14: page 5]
Git; Hash:; ZSWatch; Comments:; Sheet Title:; File Name:; Watch-DevKit-HW; ZSWatch Watch-DevKit; Company:; CHECKED; Variant:; Board Name:; ZSWatch-Watch.kicad_pcb; Daniel Kampert; Designer:; Project Name:; Date:; + (Unreleased); Revision:

Top Test Points (Scale 1:1)

# Bottom Test Points (Scale 1:1)

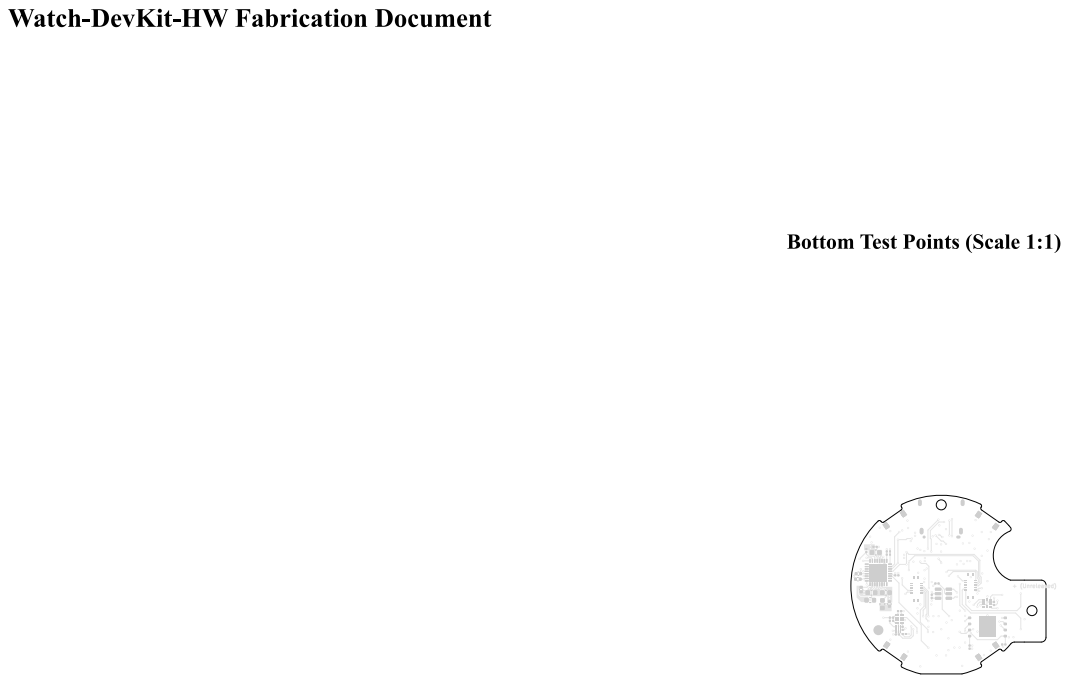
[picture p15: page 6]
Git; Hash:; ZSWatch; Comments:; Sheet Title:; File Name:; Watch-DevKit-HW; ZSWatch Watch-DevKit; Company:; CHECKED; Variant:; Board Name:; ZSWatch-Watch.kicad_pcb; Daniel Kampert; Designer:; Project Name:; Date:; + (Unreleased); Revision:

Bottom Test Points (Scale 1:1)

# F.Cu (Scale 1:1)

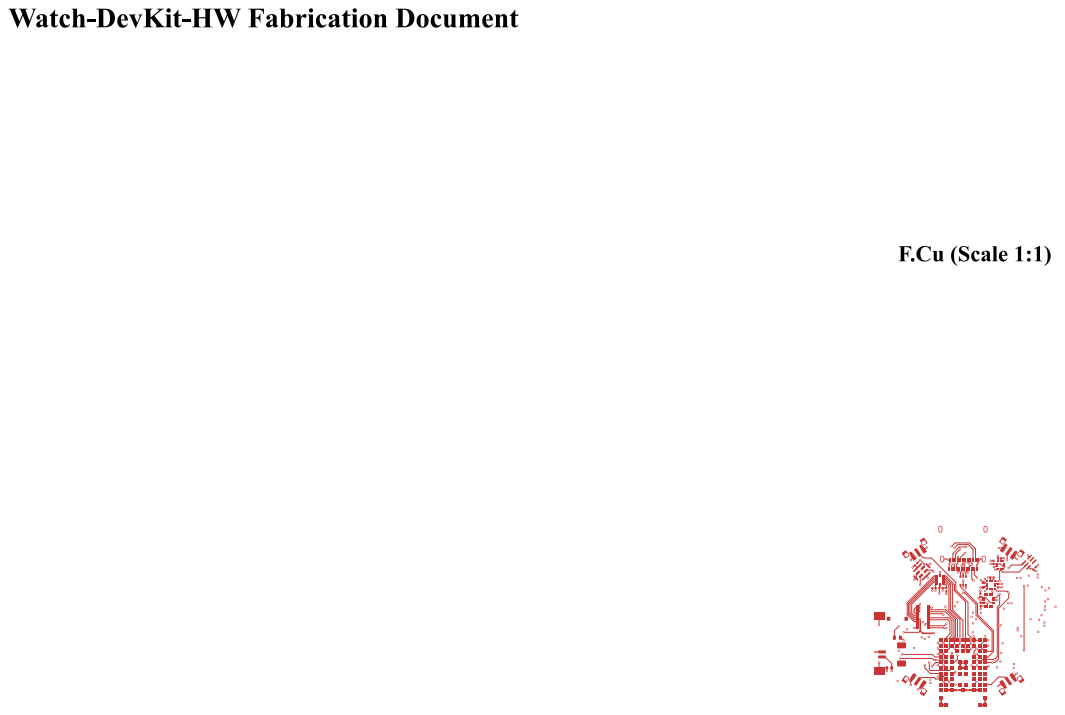
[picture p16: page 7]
Git; Hash:; ZSWatch; Comments:; F.Cu (Scale 1:1); Sheet Title:; File Name:; Watch-DevKit-HW; ZSWatch Watch-DevKit; Company:; CHECKED; Variant:; Board Name:; ZSWatch-Watch.kicad_pcb; Daniel Kampert; Designer:; Project Name:; Date:; + (Unreleased); Revision:

# Inner1 (Scale 1:1)

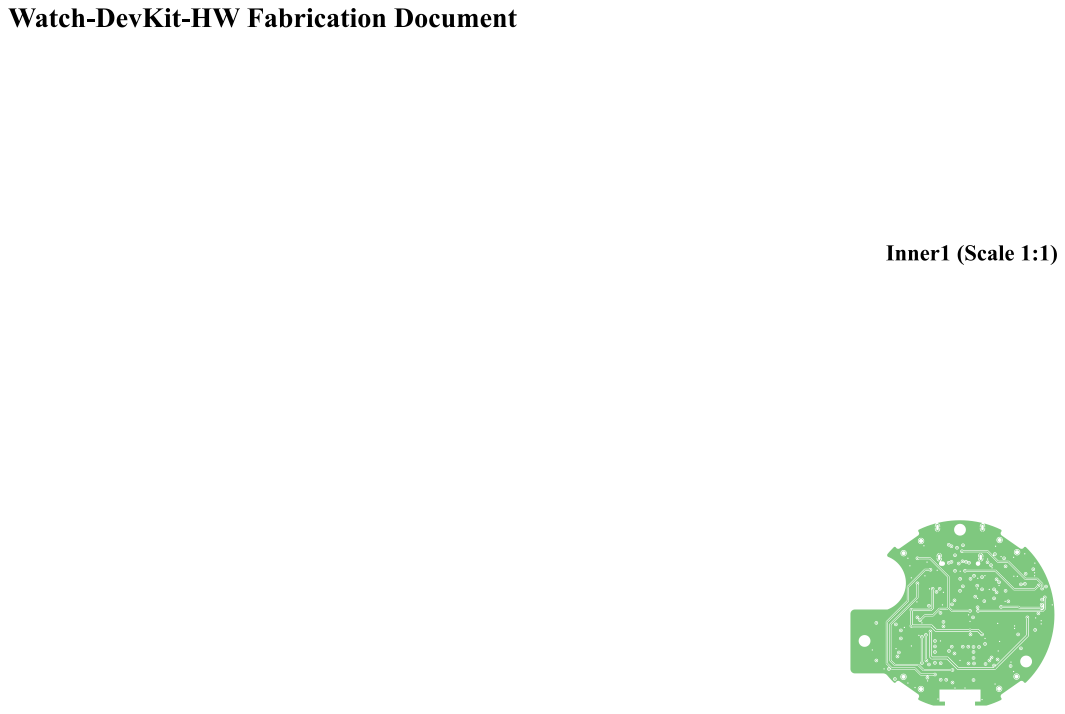
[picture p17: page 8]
Git; Hash:; ZSWatch; Comments:; Inner1 (Scale 1:1); Sheet Title:; File Name:; Watch-DevKit-HW; ZSWatch Watch-DevKit; Company:; CHECKED; Variant:; Board Name:; ZSWatch-Watch.kicad_pcb; Daniel Kampert; Designer:; Project Name:; Date:; + (Unreleased); Revision:

# Inner2 (Scale 1:1)

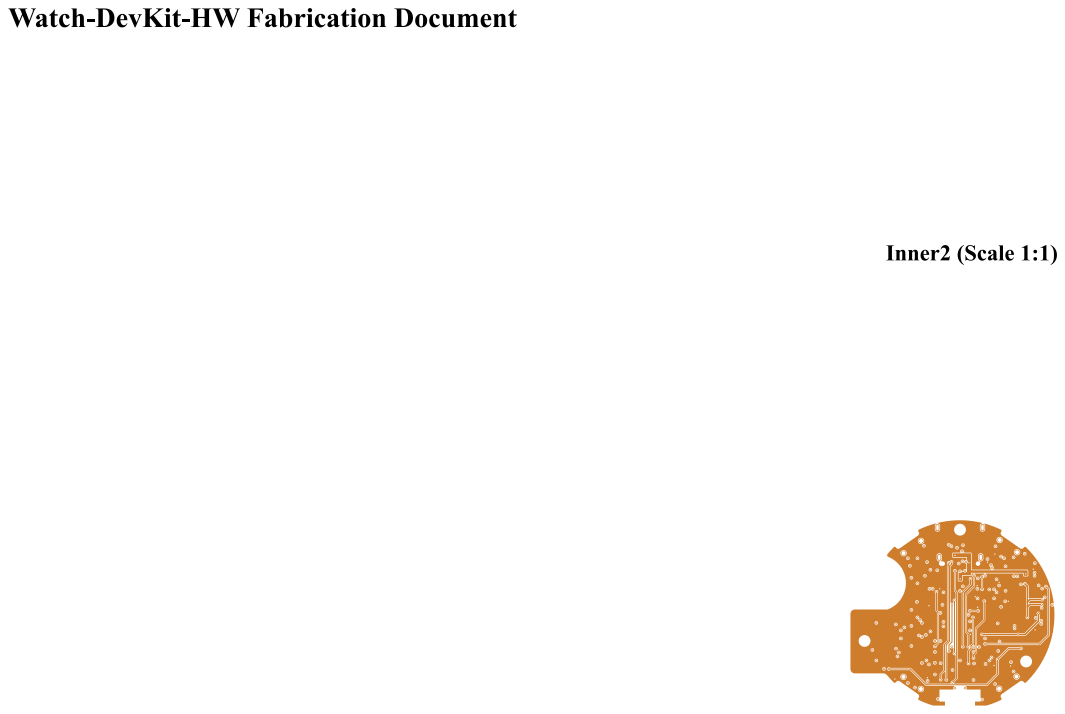
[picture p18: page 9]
Git; Hash:; ZSWatch; Comments:; Inner2 (Scale 1:1); Sheet Title:; File Name:; Watch-DevKit-HW; ZSWatch Watch-DevKit; Company:; CHECKED; Variant:; Board Name:; ZSWatch-Watch.kicad_pcb; Daniel Kampert; Designer:; Project Name:; Date:; + (Unreleased); Revision:

# B.Cu (Scale 1:1)

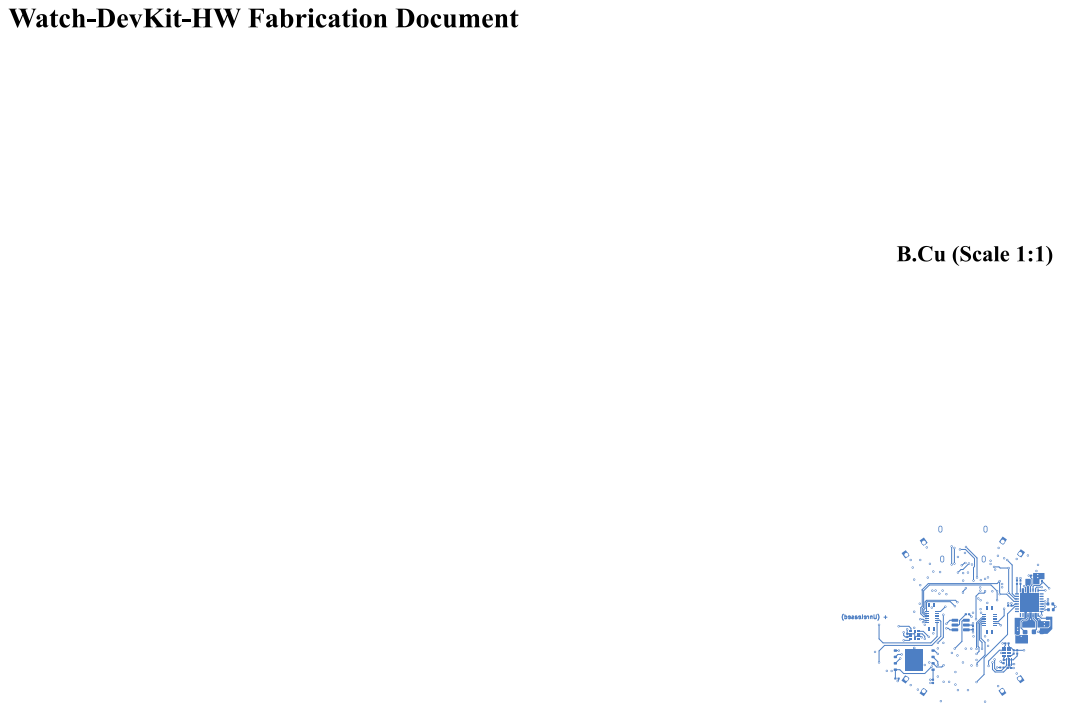
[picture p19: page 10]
Git; Hash:; ZSWatch; Comments:; B.Cu (Scale 1:1); Sheet Title:; File Name:; Watch-DevKit-HW; ZSWatch Watch-DevKit; Company:; CHECKED; Variant:; Board Name:; ZSWatch-Watch.kicad_pcb; Daniel Kampert; Designer:; Project Name:; Date:; + (Unreleased); Revision:

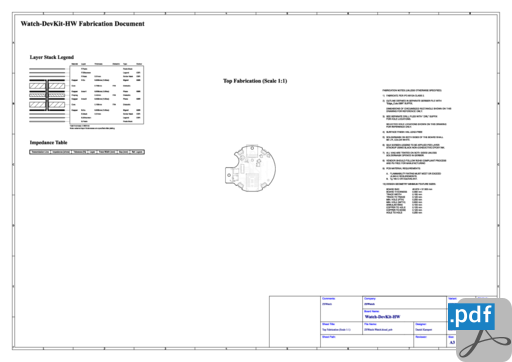
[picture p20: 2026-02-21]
production/watch-CHECKED/HTML/images/cat_pdf_fabrication_ZSWatch-Watch-fabrication.png

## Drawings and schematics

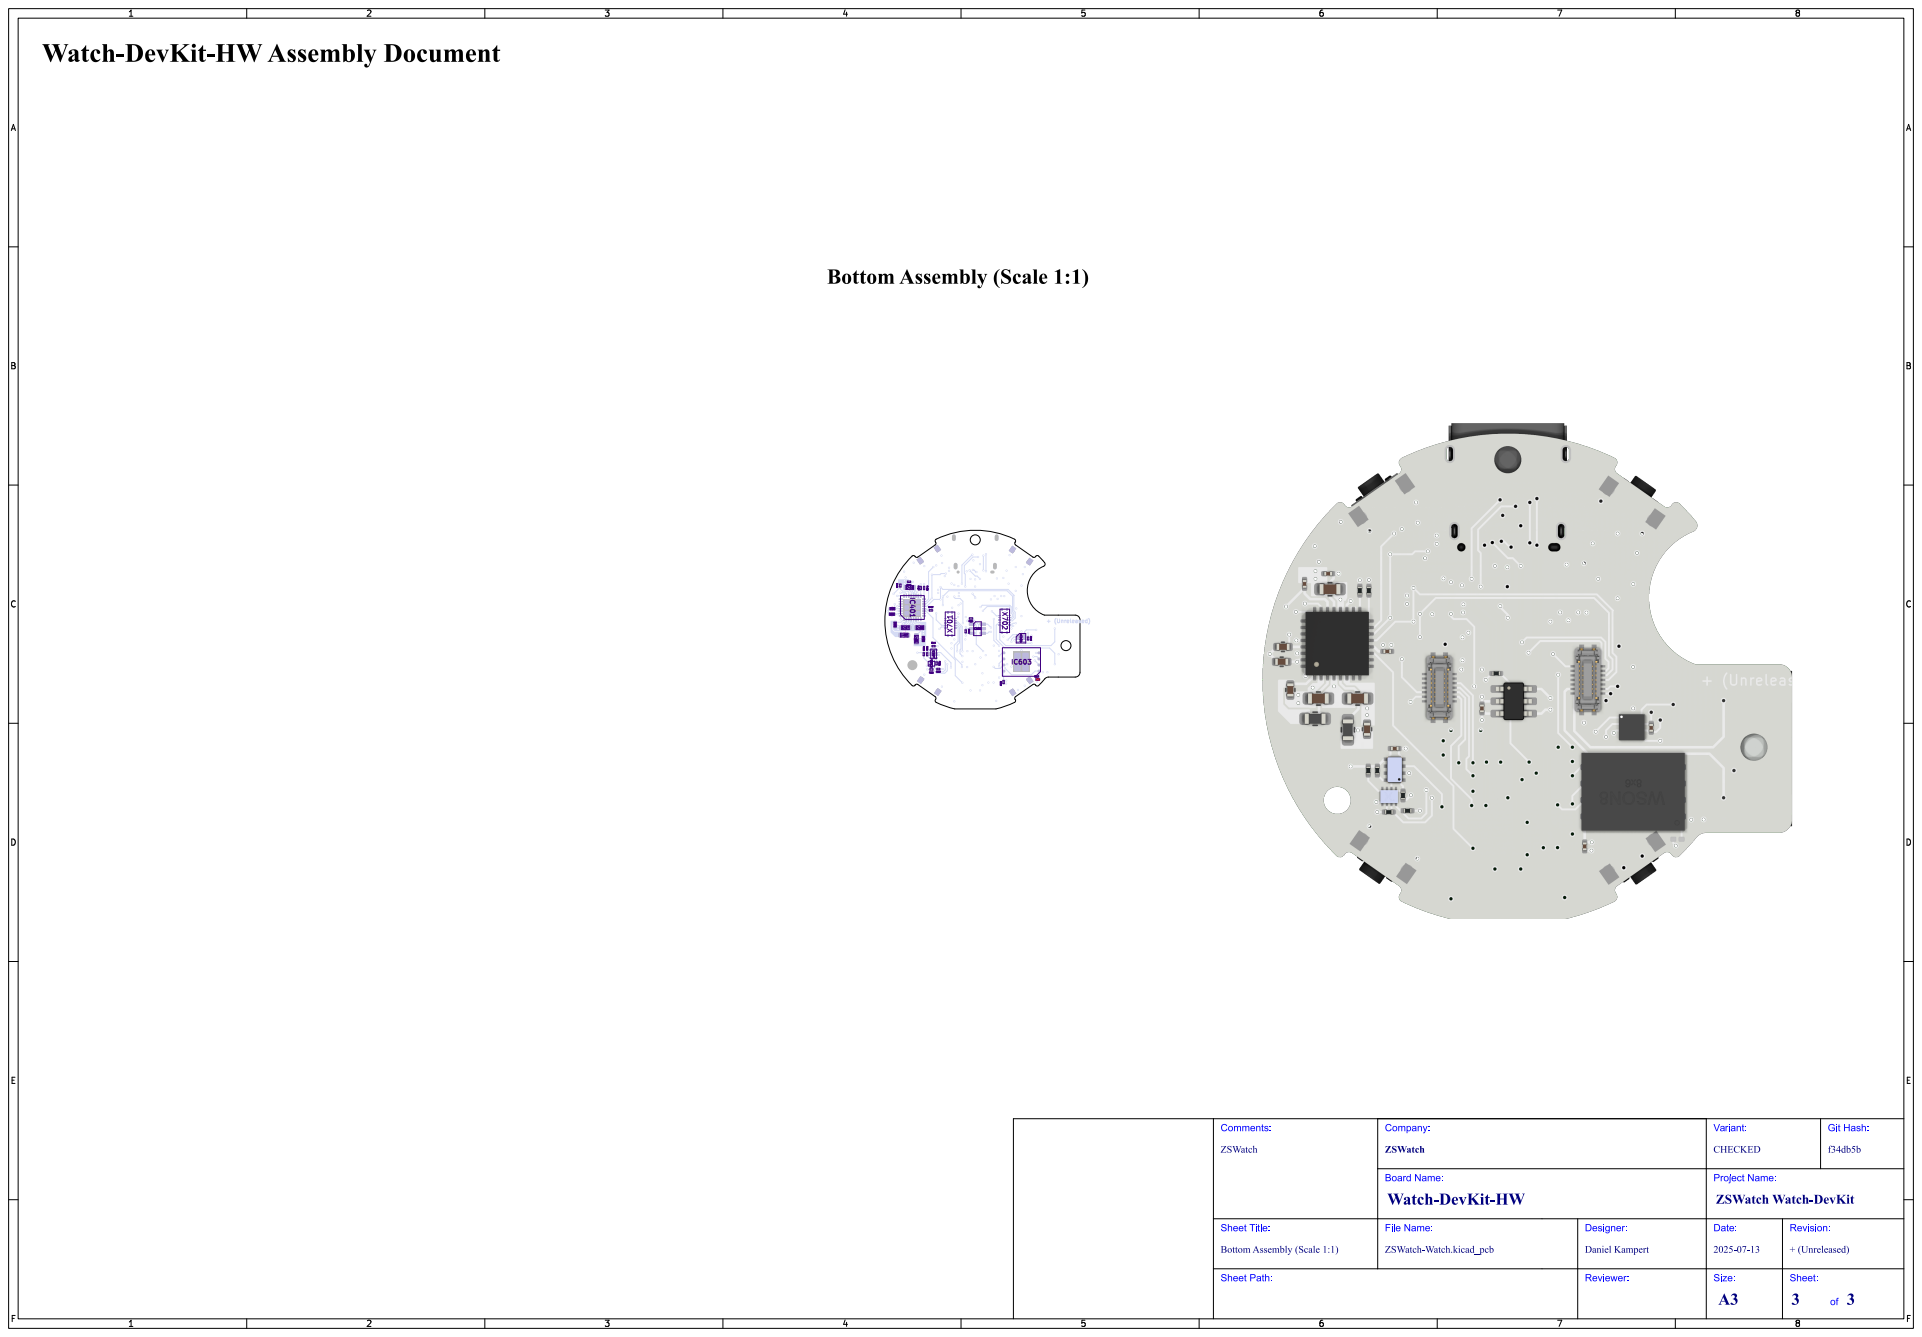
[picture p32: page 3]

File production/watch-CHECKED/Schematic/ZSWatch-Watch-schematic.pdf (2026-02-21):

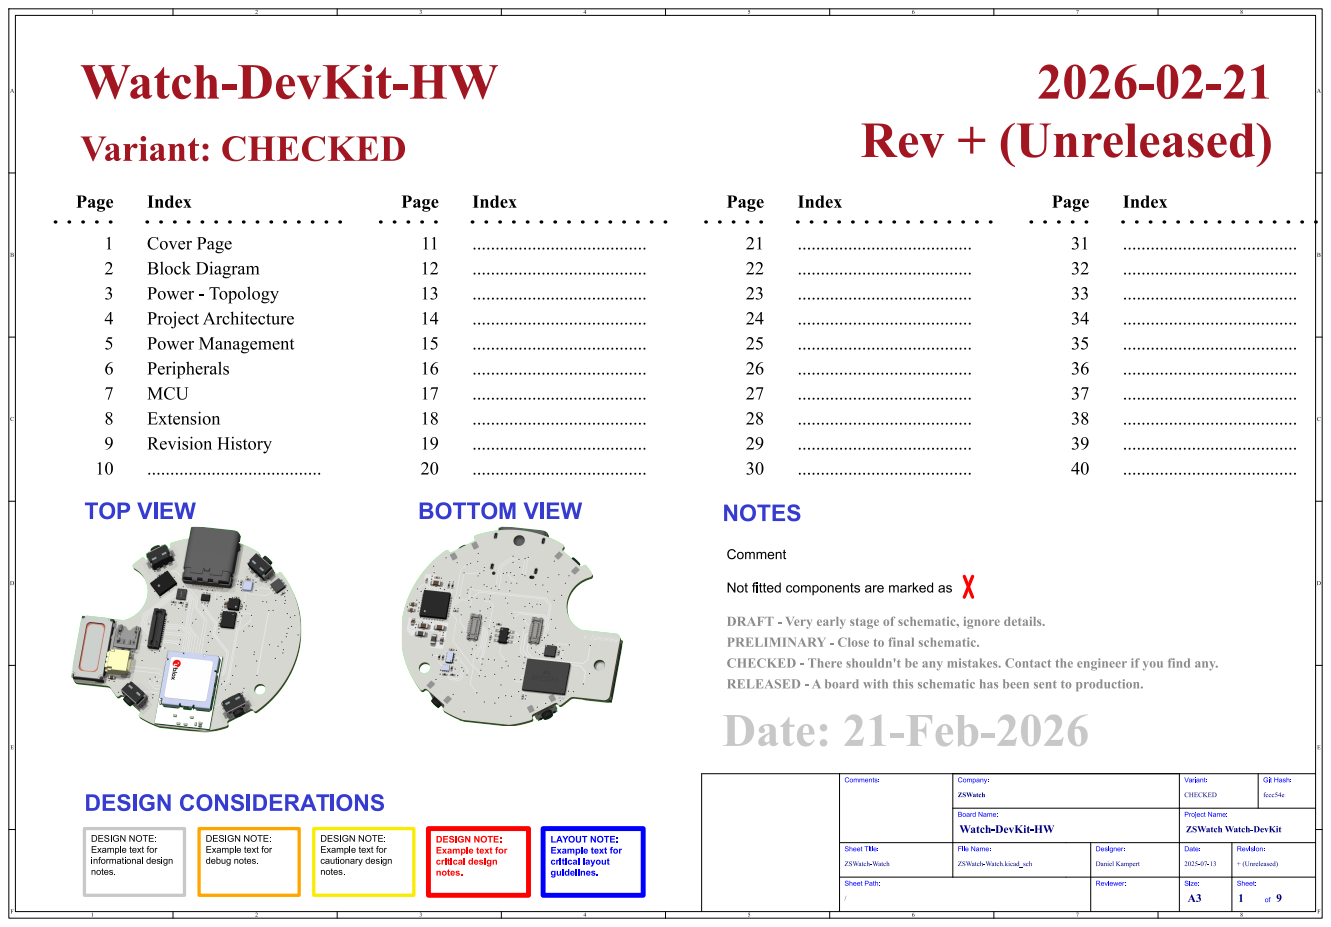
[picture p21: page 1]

...................................... PRELIMINARY - Closetofinal schematic.
CHECKED - Thereshouldn'tbeanymistakes.Contacttheengineerif youfindany. ......................................

Not fitted components are marked as

DRAFT - Veryearlystageof schematic,ignoredetails.

Revision: + (Unreleased) Date: Project Name: 2025-07-13 Reviewer: Designer:

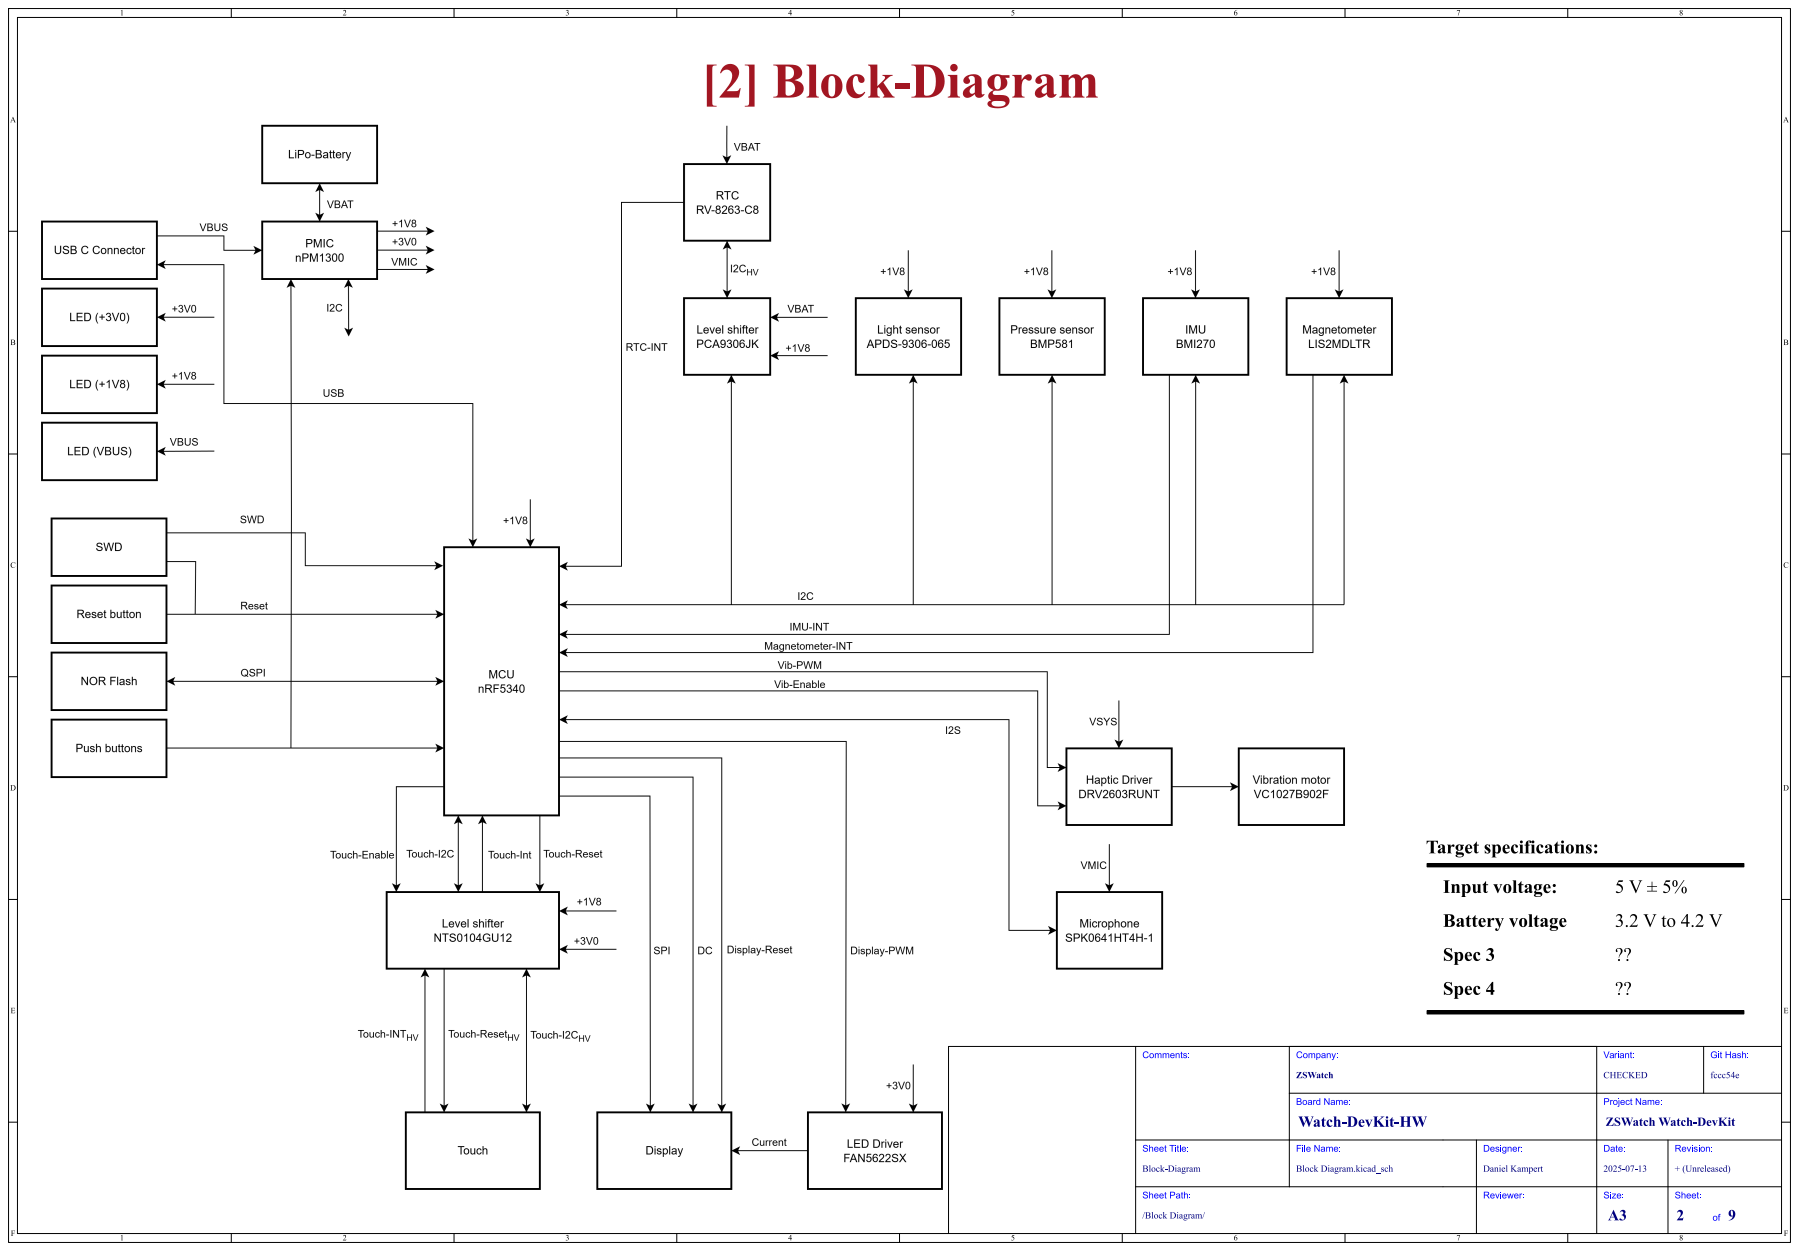
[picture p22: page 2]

/Block Diagram/ Sheet Path: Block-Diagram

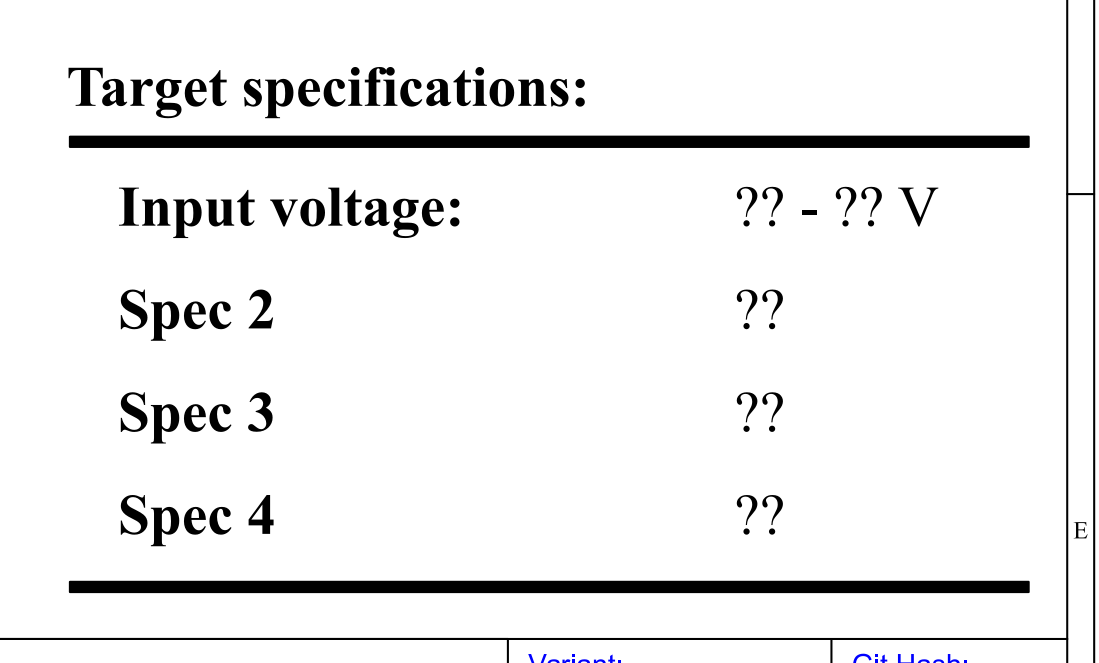
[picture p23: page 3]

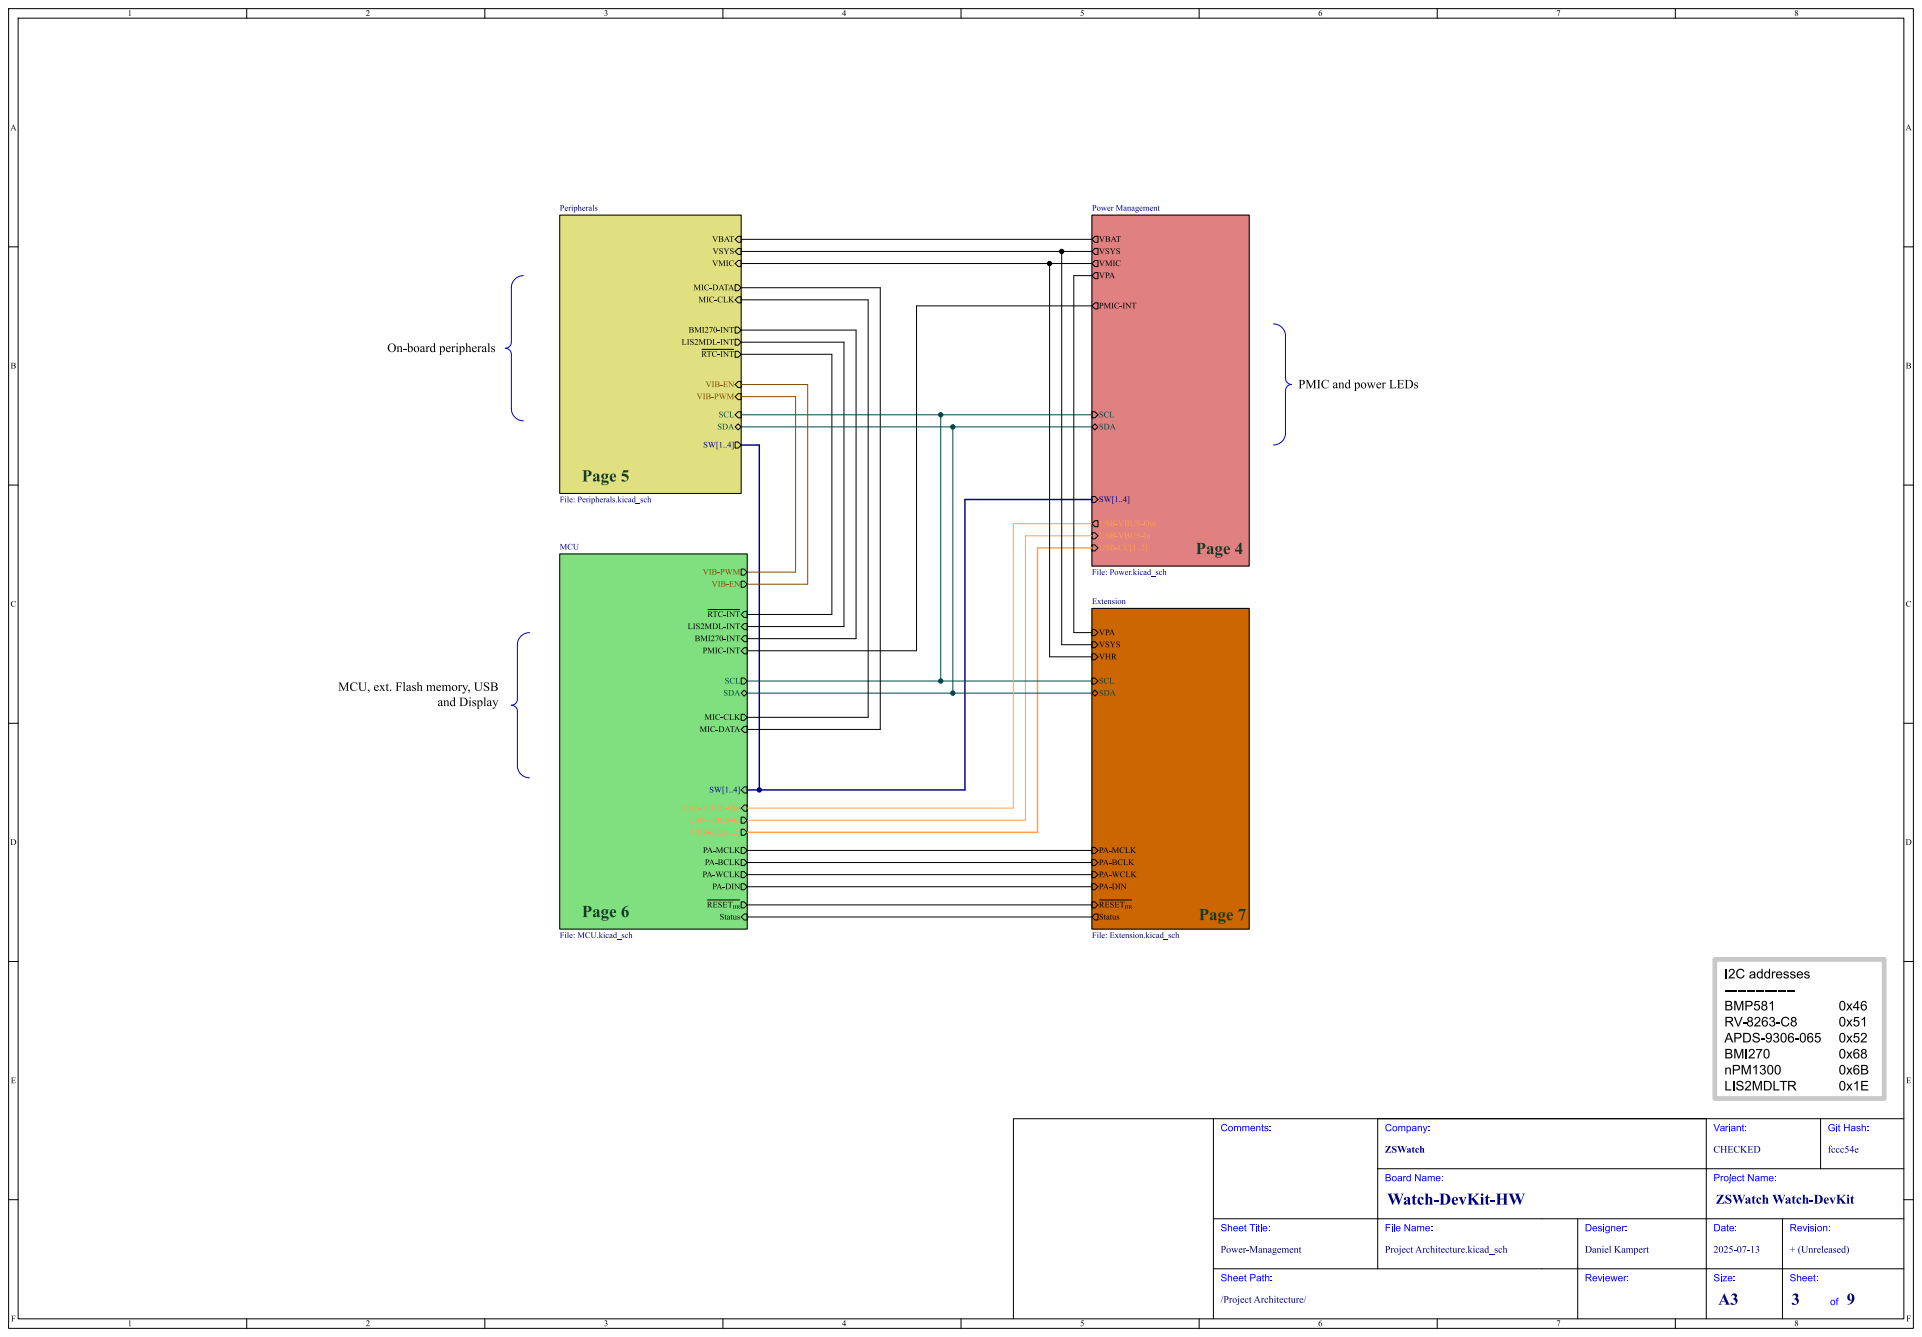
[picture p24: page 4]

PowerManagement File: Power.kicad_sch SCL
SW[1..4] VBAT VSYS

VBAT USB-VBUS-In USB-CC[1..2] USB-VBUS-Out SW[1..4] VMIC
VSYS

LIS2MDL-INT BMI270-INT MIC-CLK MIC-DATA

~{RTC-INT} VIB-EN

PA-MCLK MCU
LIS2MDL-INT BMI270-INT PMIC-INT MIC-DATA MIC-CLK USB-VBUS-In USB-CC[1..2] USB-VBUS-Out SW[1..4]

VIB-PWM

MCU, ext.Flashmemory,USB

PA-MCLK
PA-BCLK
PA-WCLK
~{RESET_{HR}} Status PA-DIN

Revision: + (Unreleased) Date: Project Name: 2025-07-13 Reviewer: Designer:

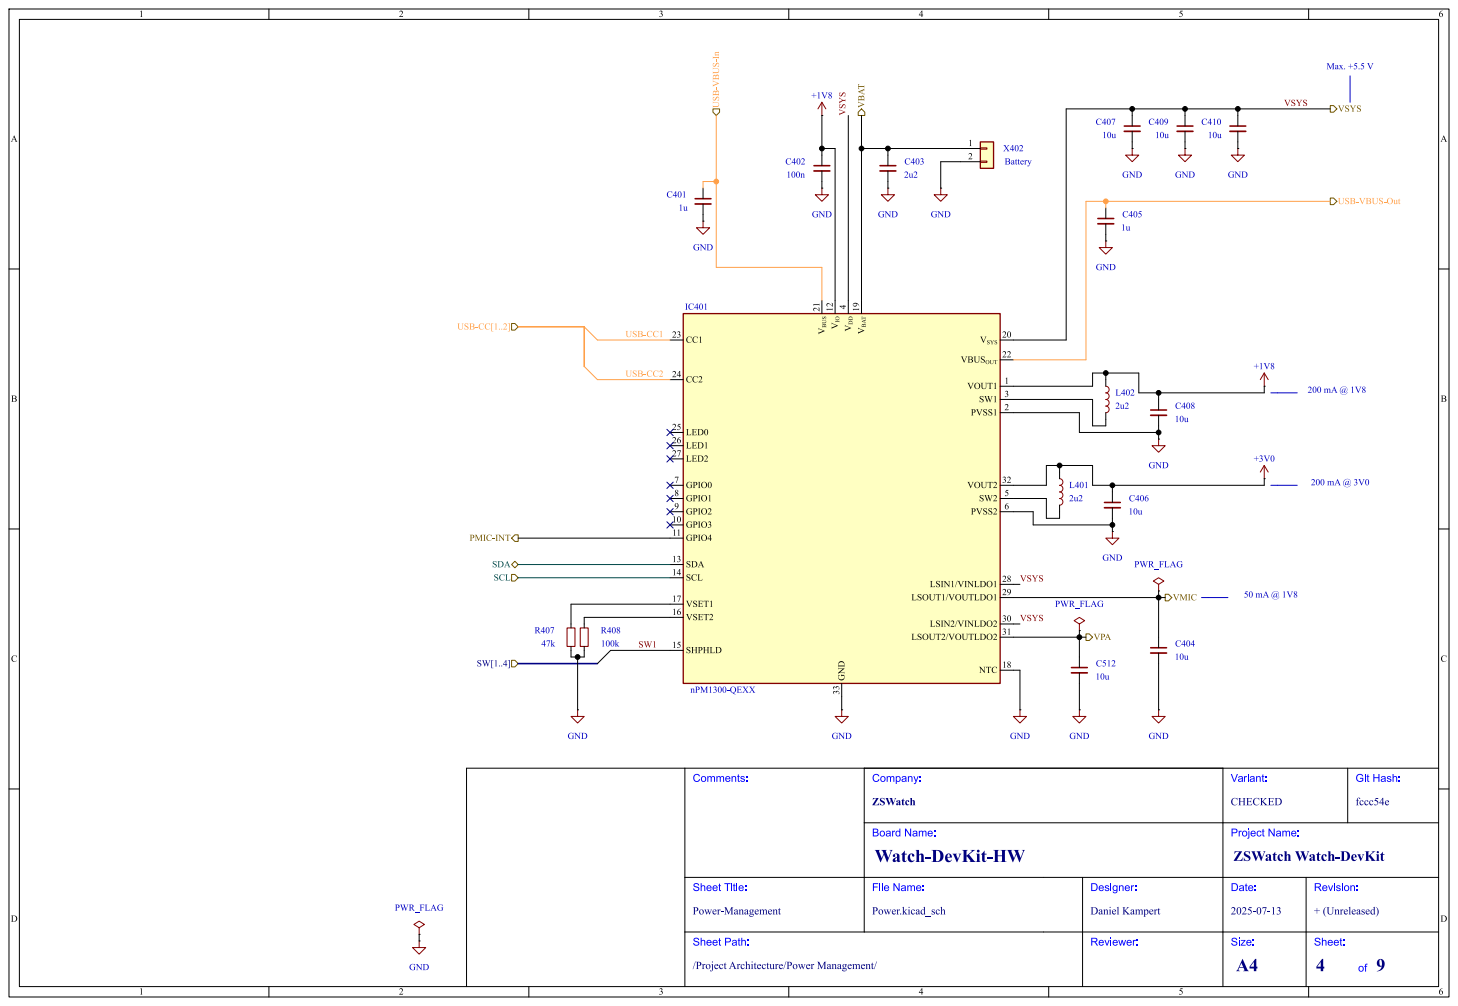
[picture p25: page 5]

USB-VBUS-Out VSYS

Revision: + (Unreleased) Date: Project Name: 2025-07-13 Reviewer: Designer:

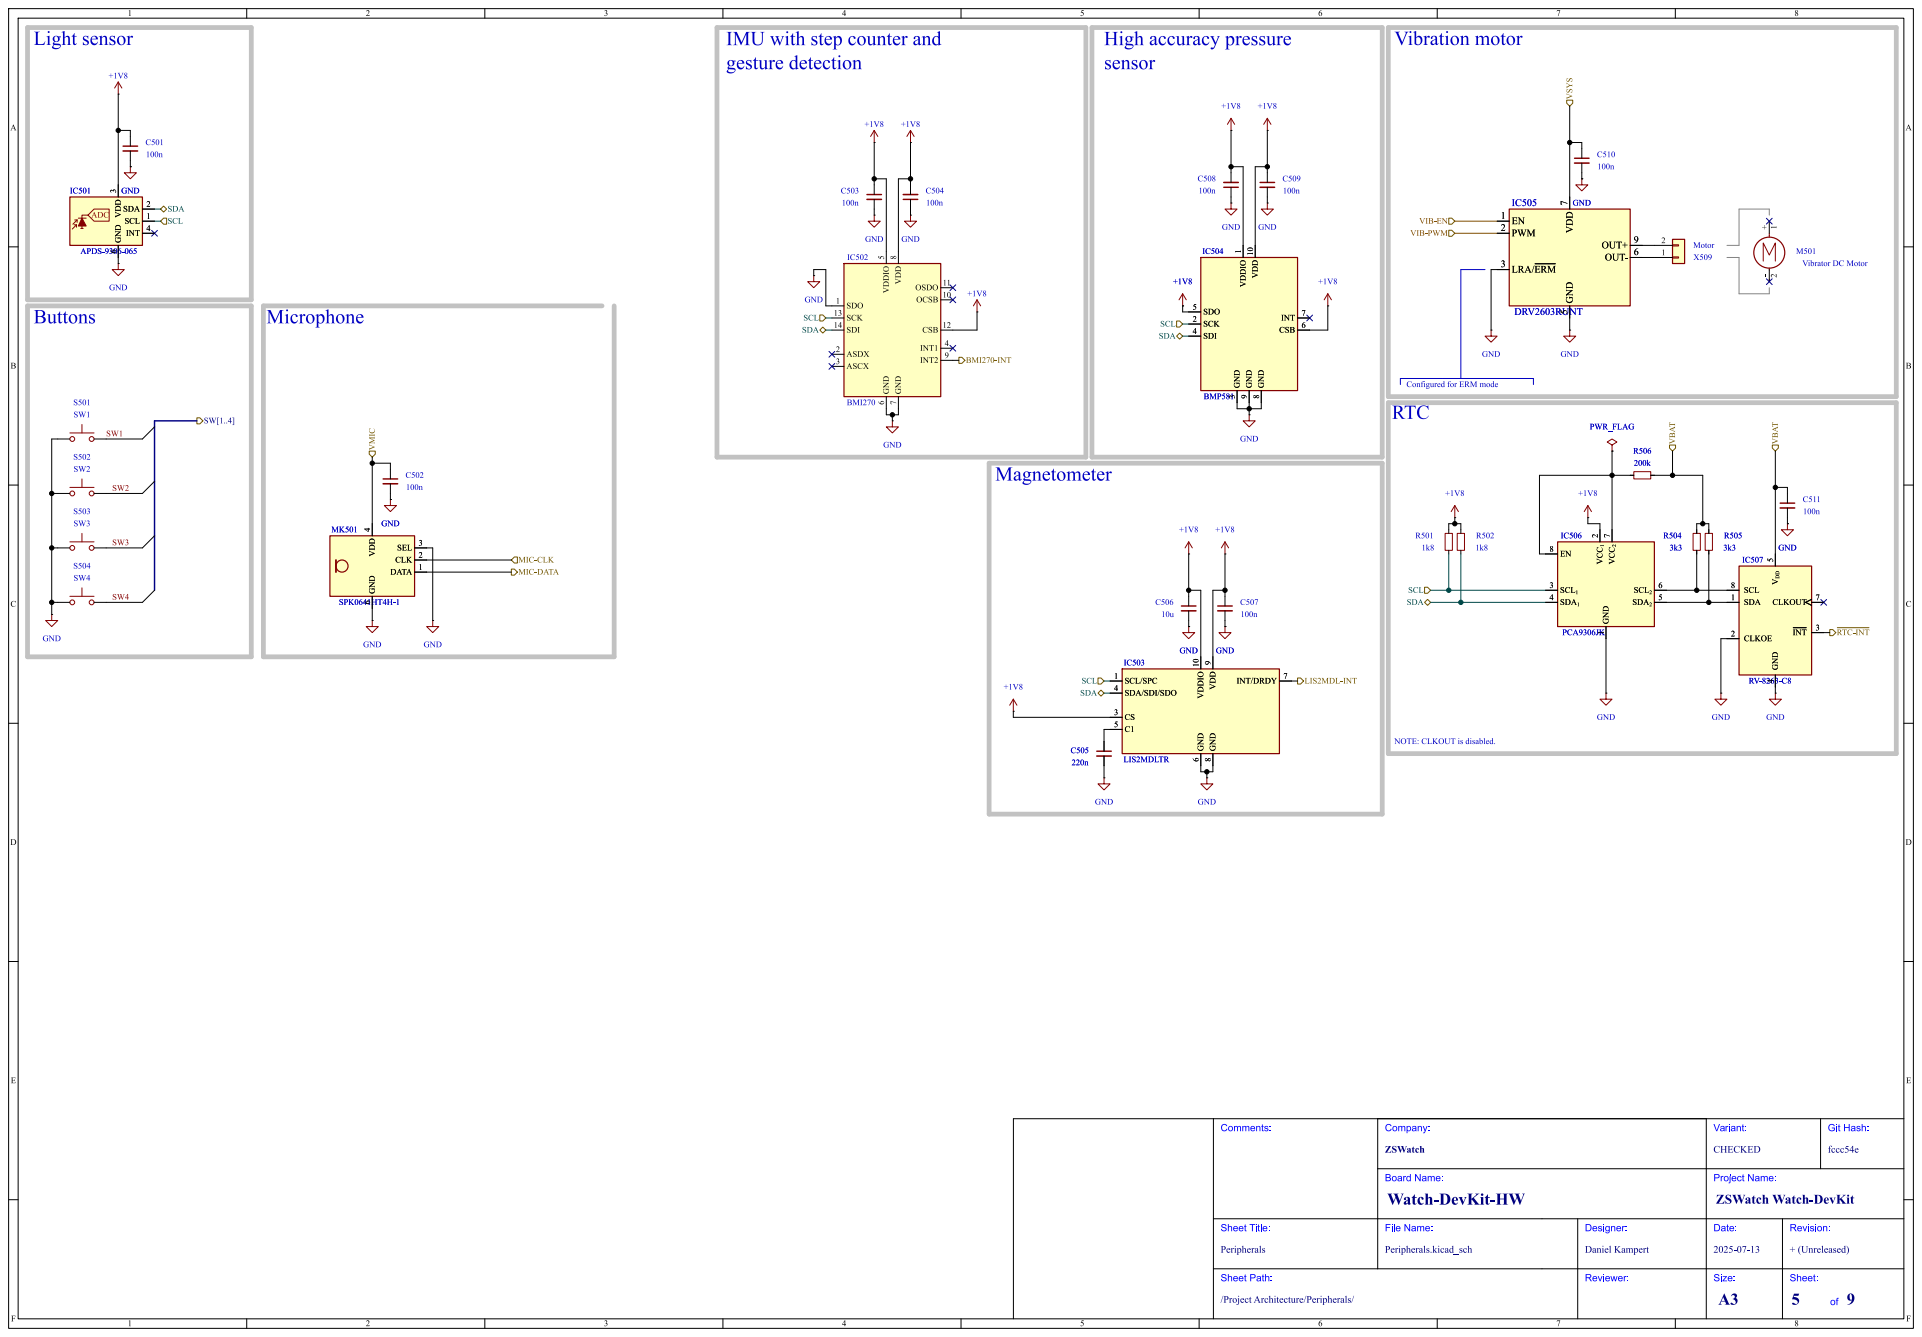
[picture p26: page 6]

NOTE: CLKOUT is disabled. Light sensor

Configuredfor ERM mode IMU with stepcounterand
gesturedetection

5 OUT+ 9 OUT- 6 GND GND

-2 M501 VibratorDC Motor SDO 1 SCK 13 SDI 14 ASDX 2 ASCX 3 VDDIO

MIC-CLK MIC-DATA

Revision: + (Unreleased) Date: Project Name: 2025-07-13 Reviewer: Designer:

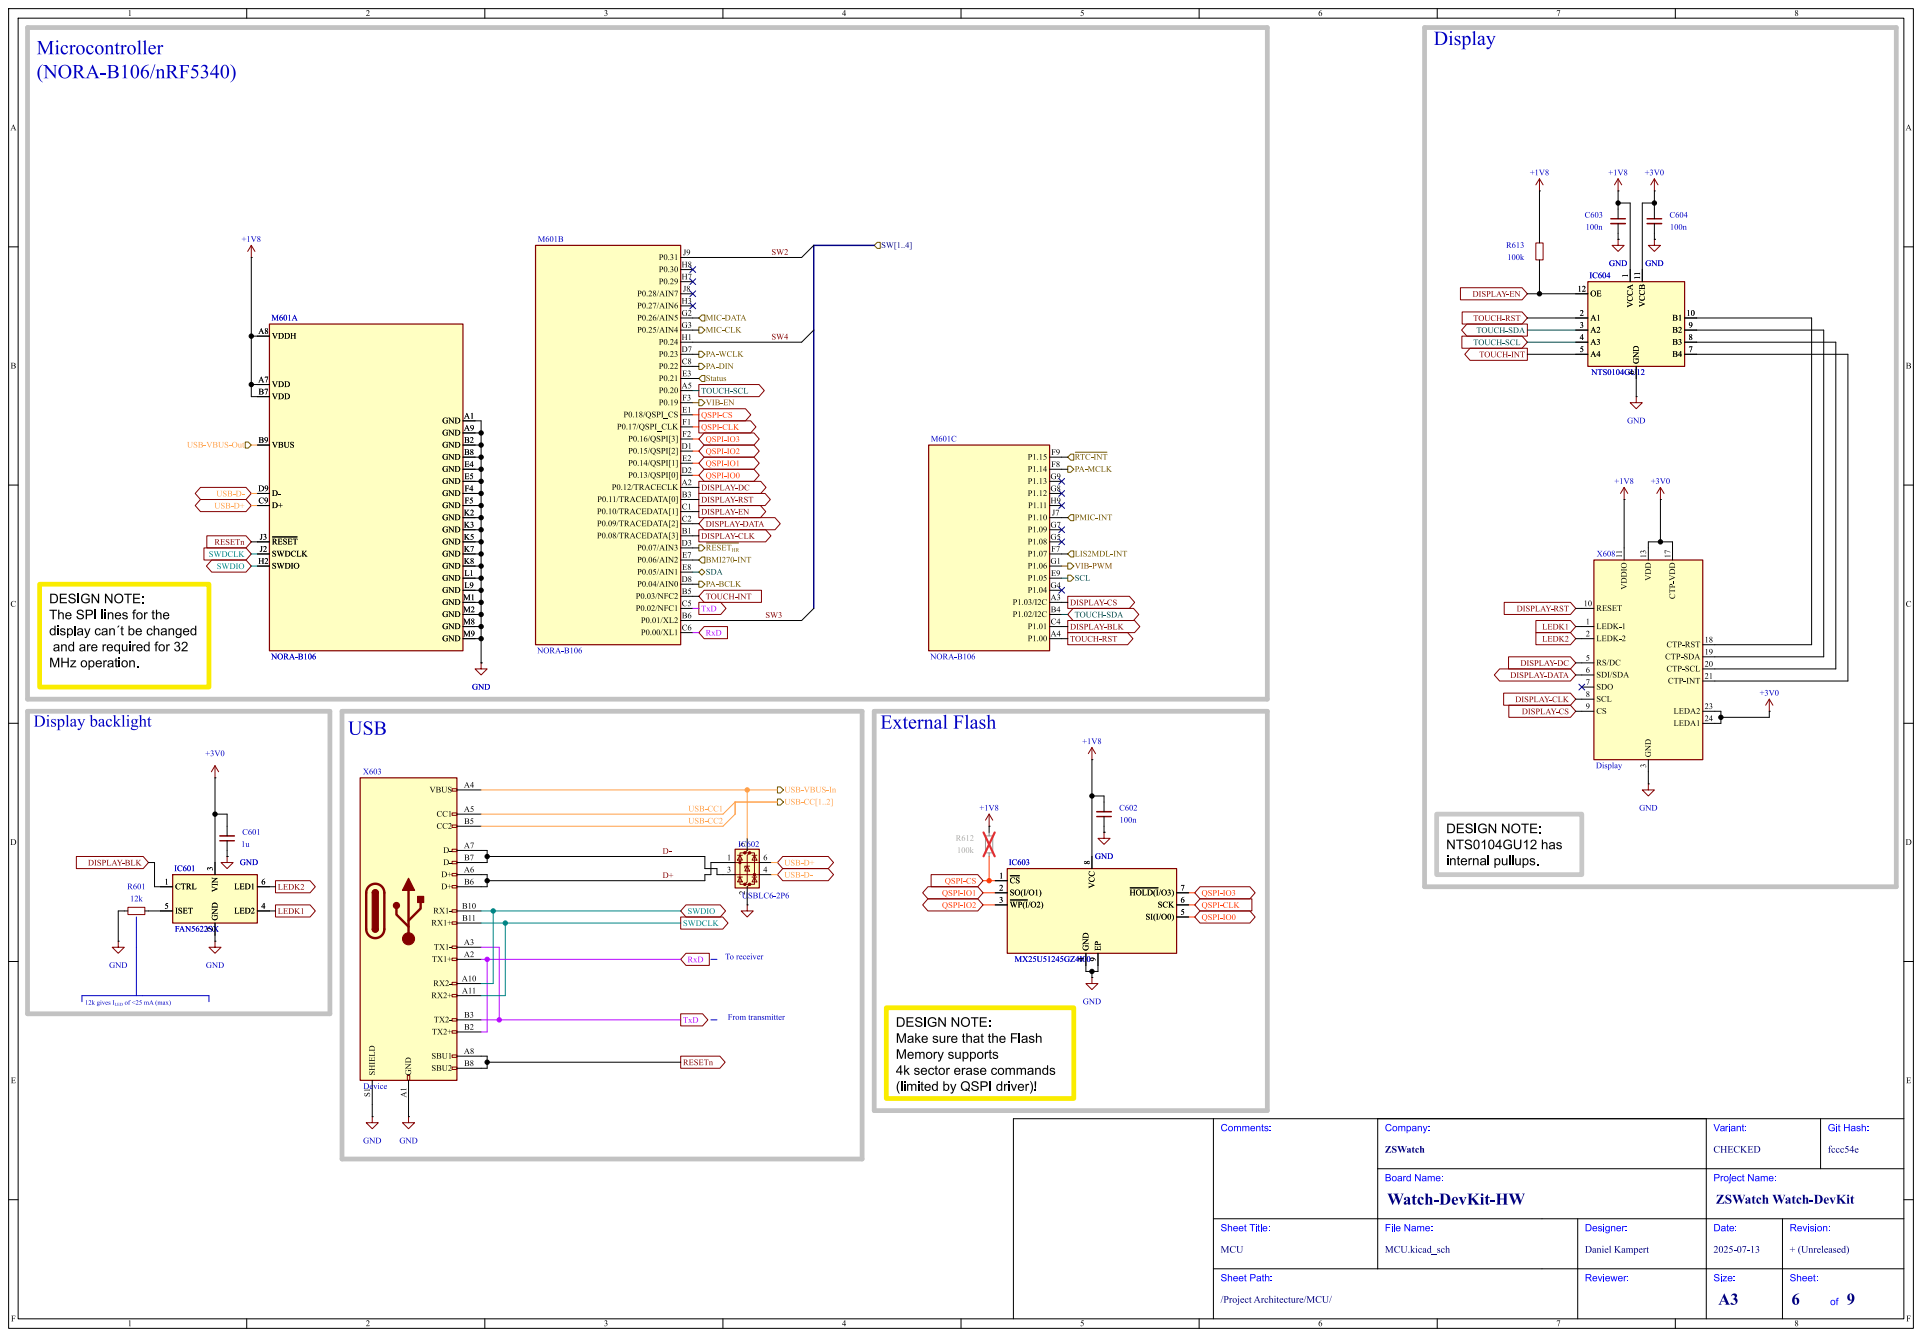
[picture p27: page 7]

PA-DIN MIC-DATA

8 B4

PMIC-INT VIB-EN QSPI-IO2 RxD

DISPLAY-CLK DISPLAY-DATA QSPI-CLK

USB-D+ USB-D- SWDCLK RESETn SWDIO

3 CTP-VDD 17 CTP-RST

The SPI lines for the
display þÿcan´t be changed
and are required for 32
MHz operation.

9 ~{HOLD(I}/O3)7 SCK 6 SI(I/O0) 5 GND IC601 FAN5622SX CTRL 1
CTRL 1

DESIGN NOTE:
Make sure that the Flash
Memory supports
4k sector erase commands
(limited by QSPI driver)!

Revision: + (Unreleased) Date: Project Name: 2025-07-13 Reviewer: Designer:

/ProjectArchitecture/MCU/ Sheet Path: MCU

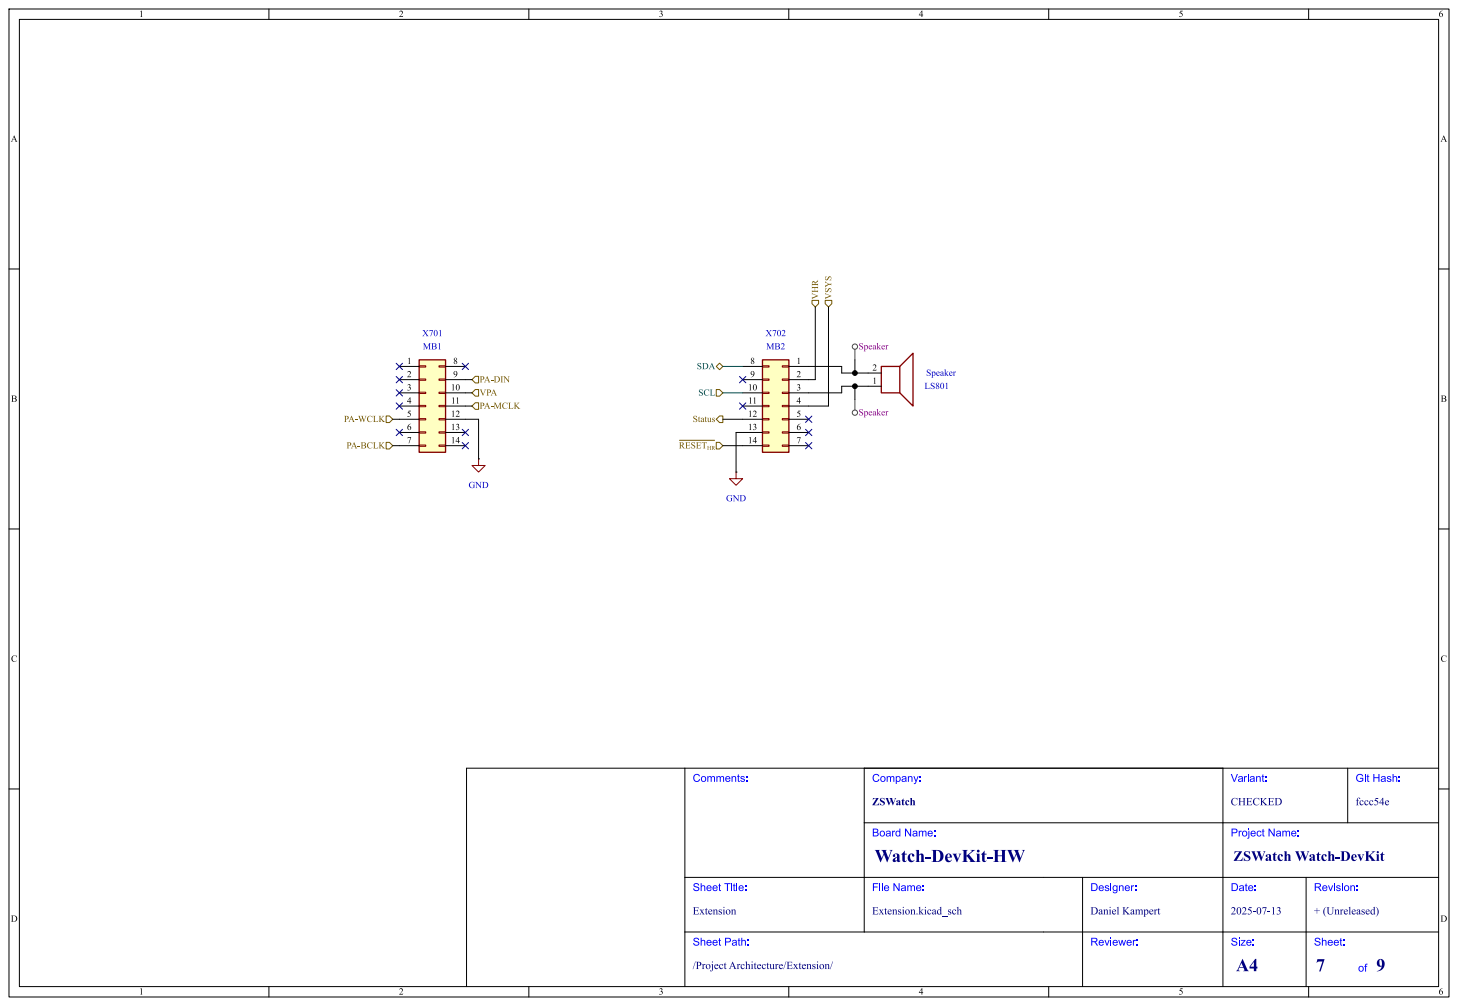
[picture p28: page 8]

Revision: + (Unreleased) Date: Project Name: 2025-07-13 Reviewer: Designer:

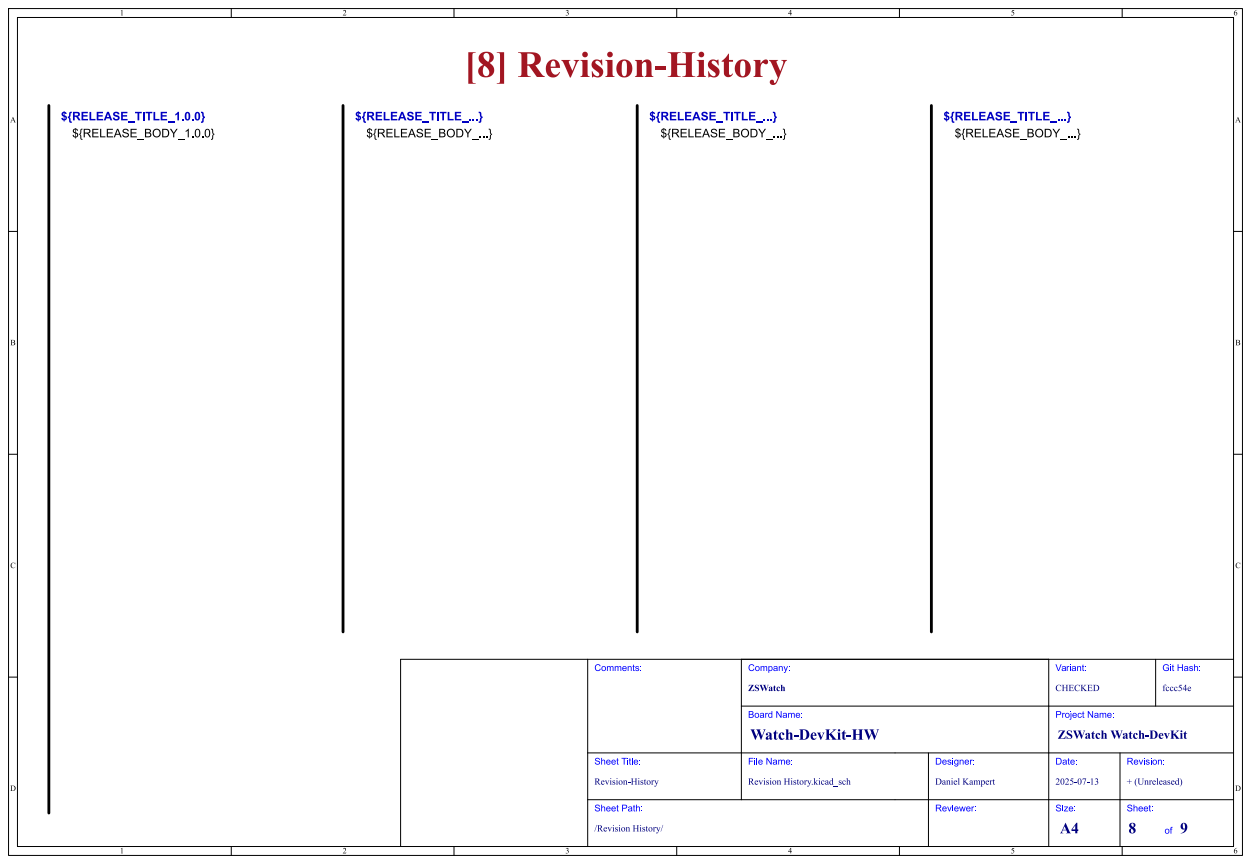
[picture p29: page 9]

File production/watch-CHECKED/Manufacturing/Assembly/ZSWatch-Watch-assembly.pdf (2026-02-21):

# Watch-DevKit-HW Assembly Document

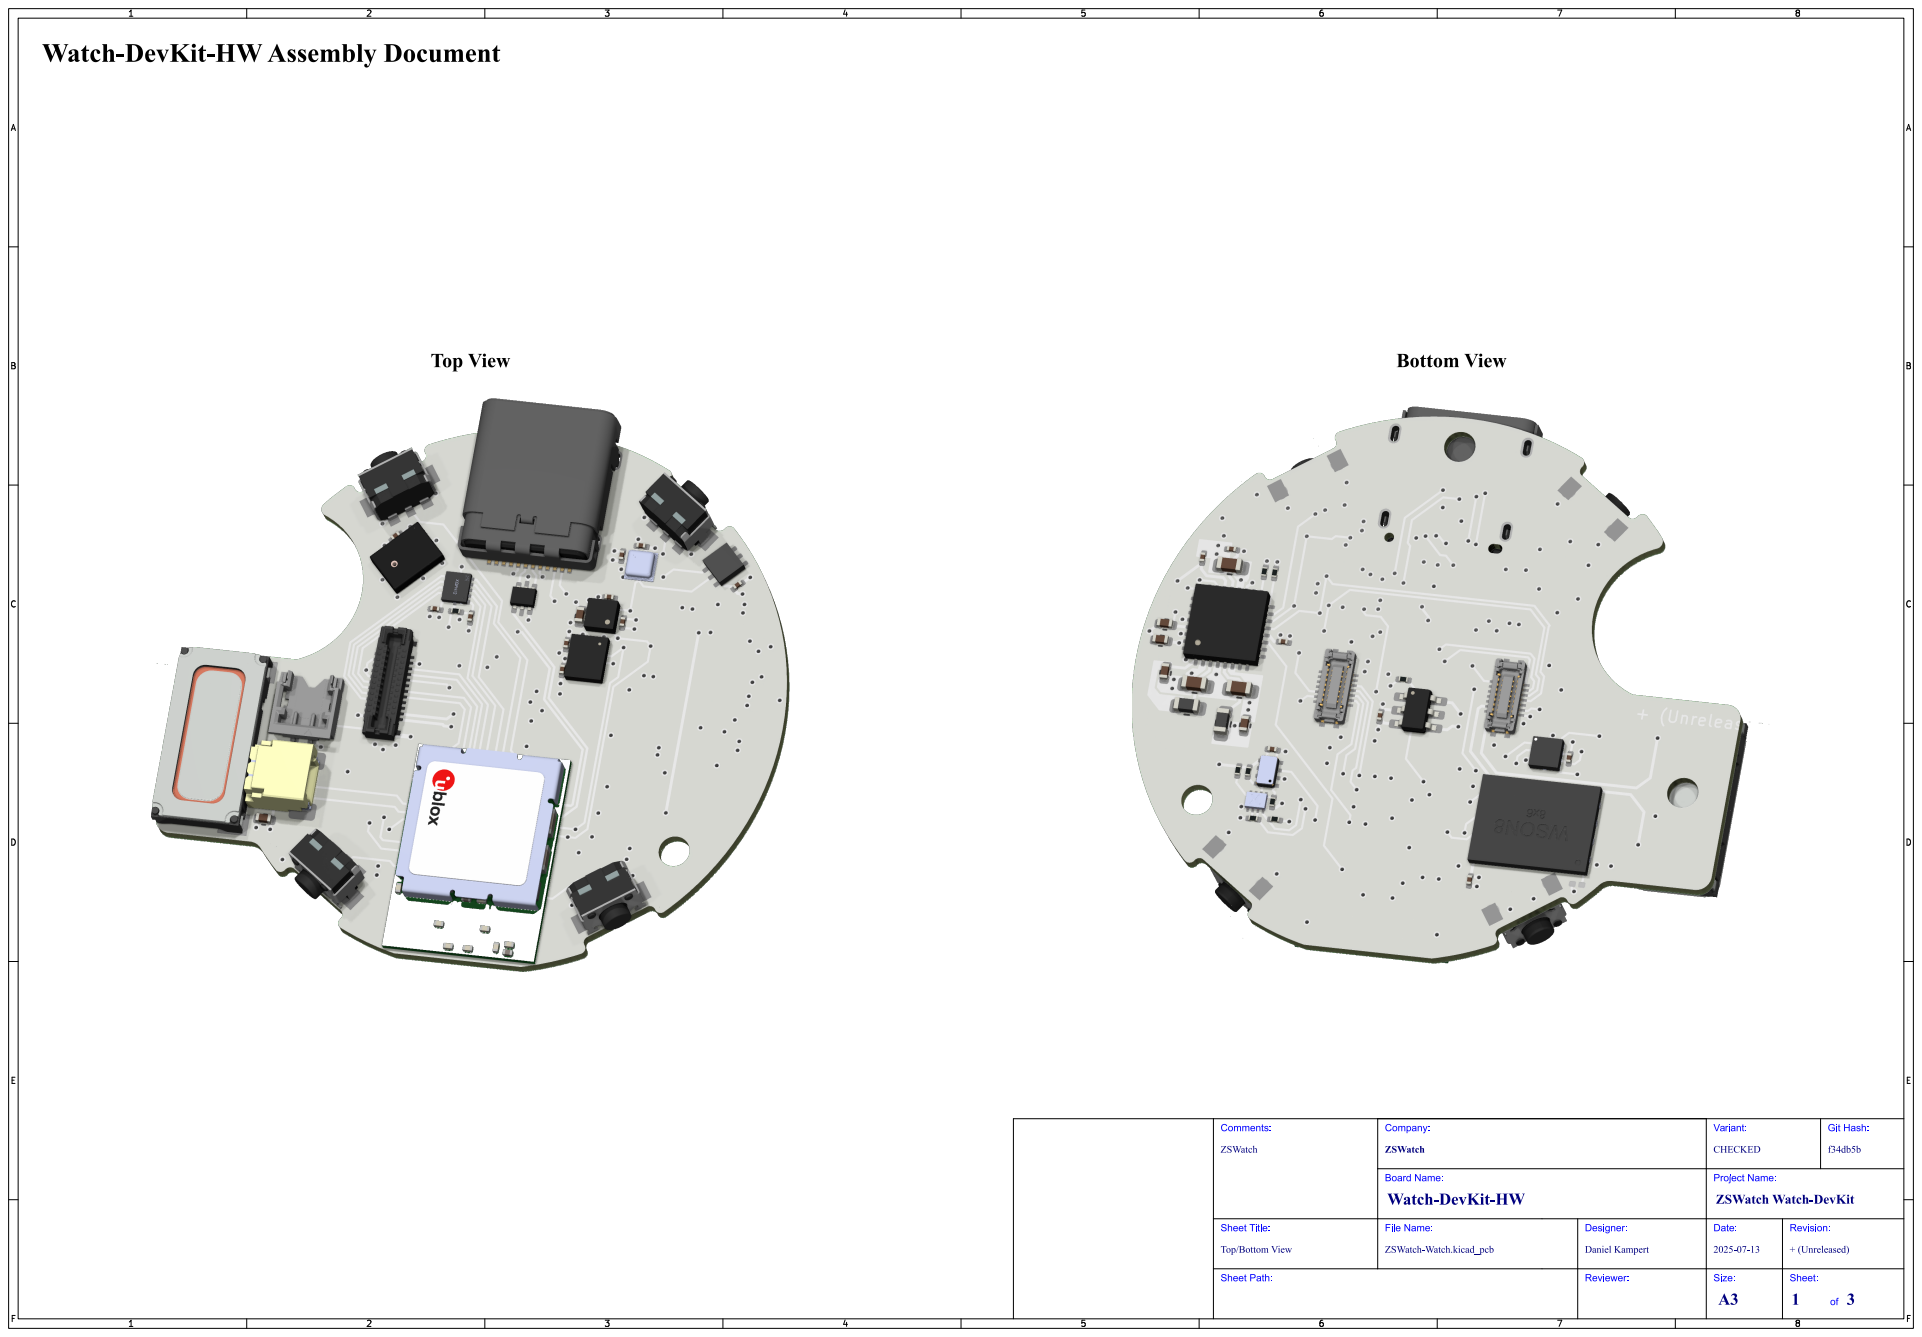
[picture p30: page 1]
Git; Hash:; ZSWatch; Comments:; Sheet Path:; Sheet Title:; File Name:; Watch-DevKit-HW; ZSWatch Watch-DevKit; Company:; CHECKED; Variant:; Board Name:; ZSWatch-Watch.kicad_pcb; Daniel Kampert; Designer:; Reviewer:; Project Name:; Date:; + (Unreleased); Revision:; Size:; Sheet:

Top/Bottom View

# Top Assembly (Scale 1:1)

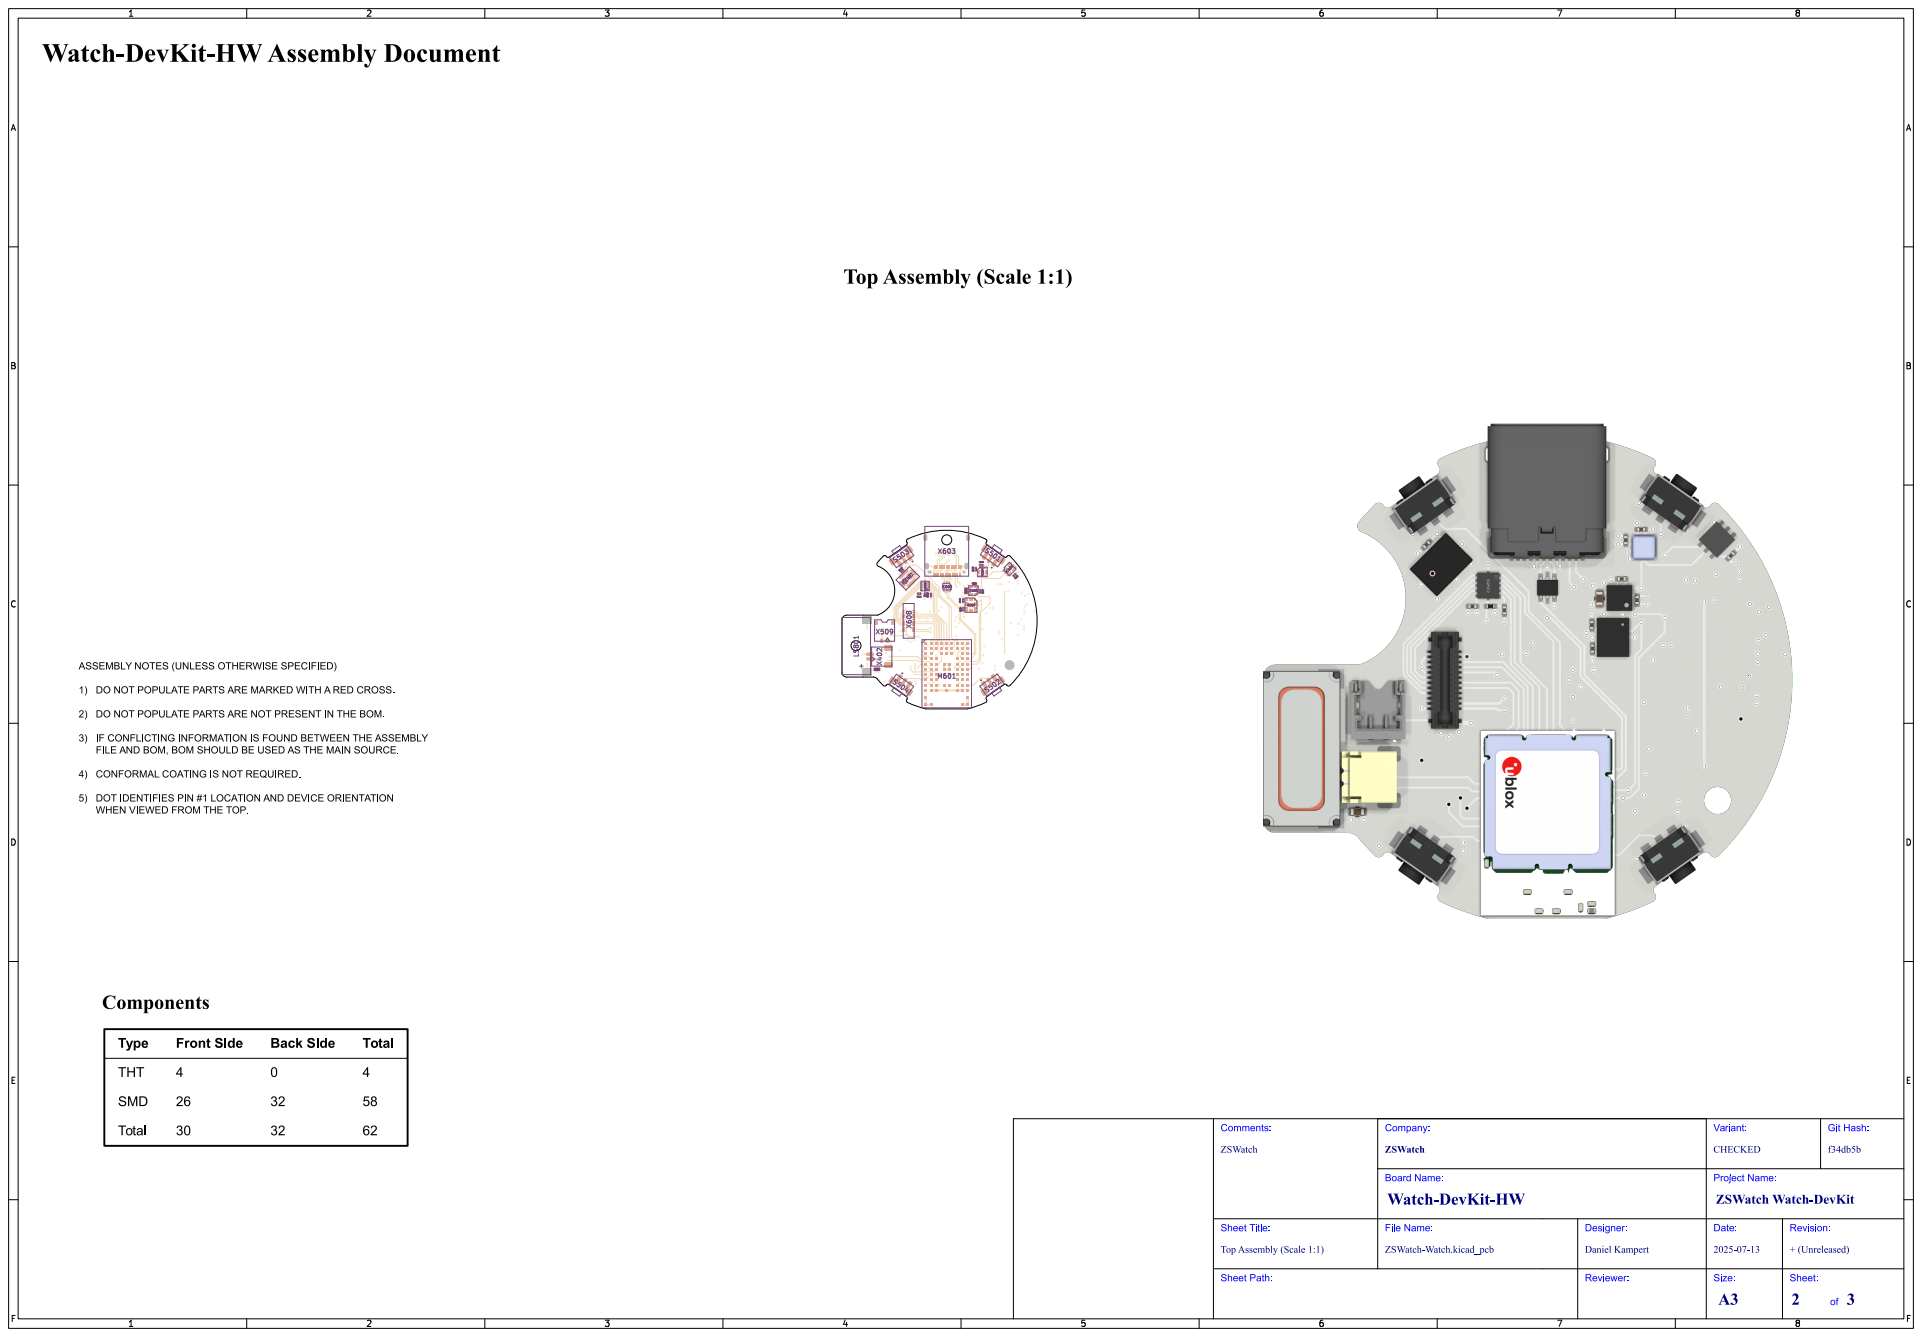
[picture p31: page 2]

# Bottom Assembly (Scale 1:1)
